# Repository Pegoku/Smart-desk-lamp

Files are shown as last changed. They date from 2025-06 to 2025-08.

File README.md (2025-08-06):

# Smart Desk Lamp

This is a home assistant controlled CWWW desk lamp with capacitive touch buttons, made with ESPHome and ESP32-C3.

## Why I made it?

I made this project as I wanted to learn more about capacitive touch sensors and how to use them with ESPHome. I also wanted to make a simple desk lamp that could be controlled with Home Assistant.

## Features

- Capacitive touch buttons to control the brightness and color temperature of the LEDs.
- Home Assistant integration.

## Images

Final Build:

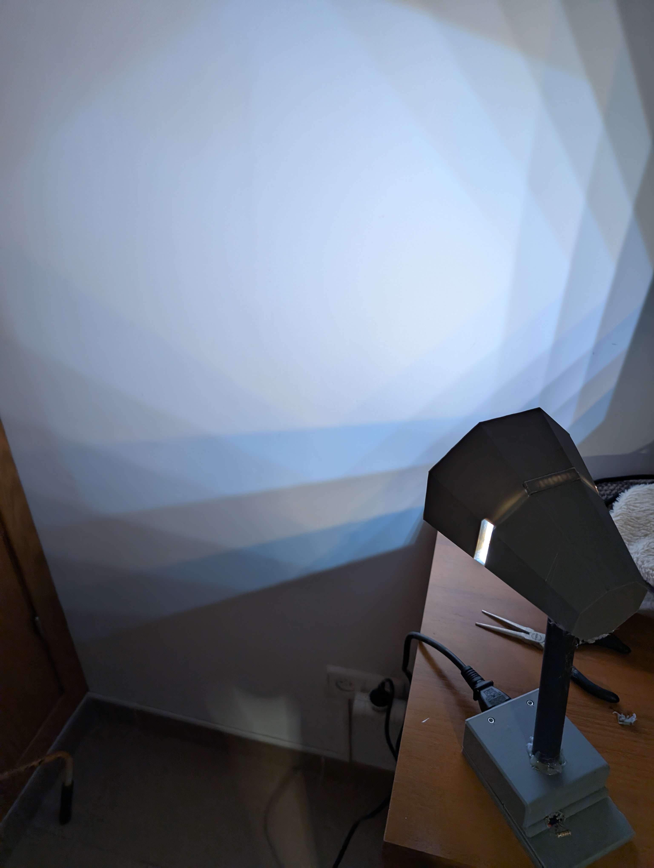
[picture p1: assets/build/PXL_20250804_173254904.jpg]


<details>
  <summary>Case/Assembly</summary>

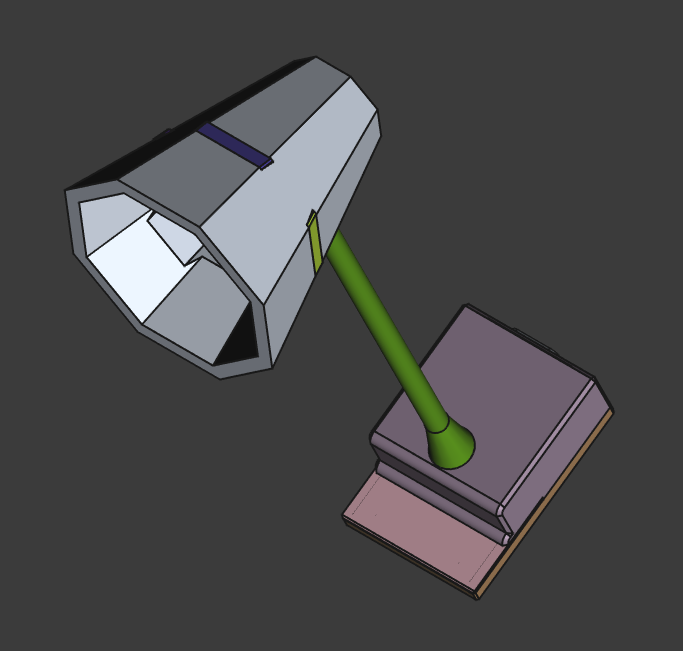
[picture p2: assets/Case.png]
Final


</details>
<details>
  <summary>Main Schematic</summary>
  
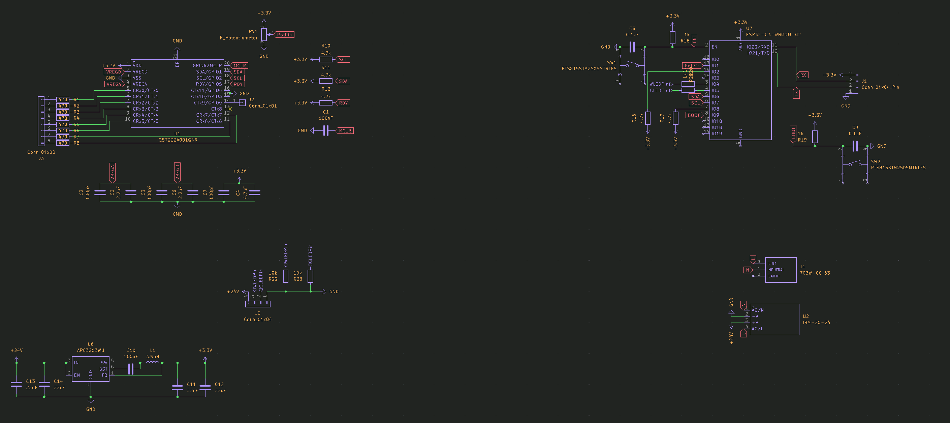
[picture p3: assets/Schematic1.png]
schematic


</details>
<details>
  <summary>Main PCB</summary>

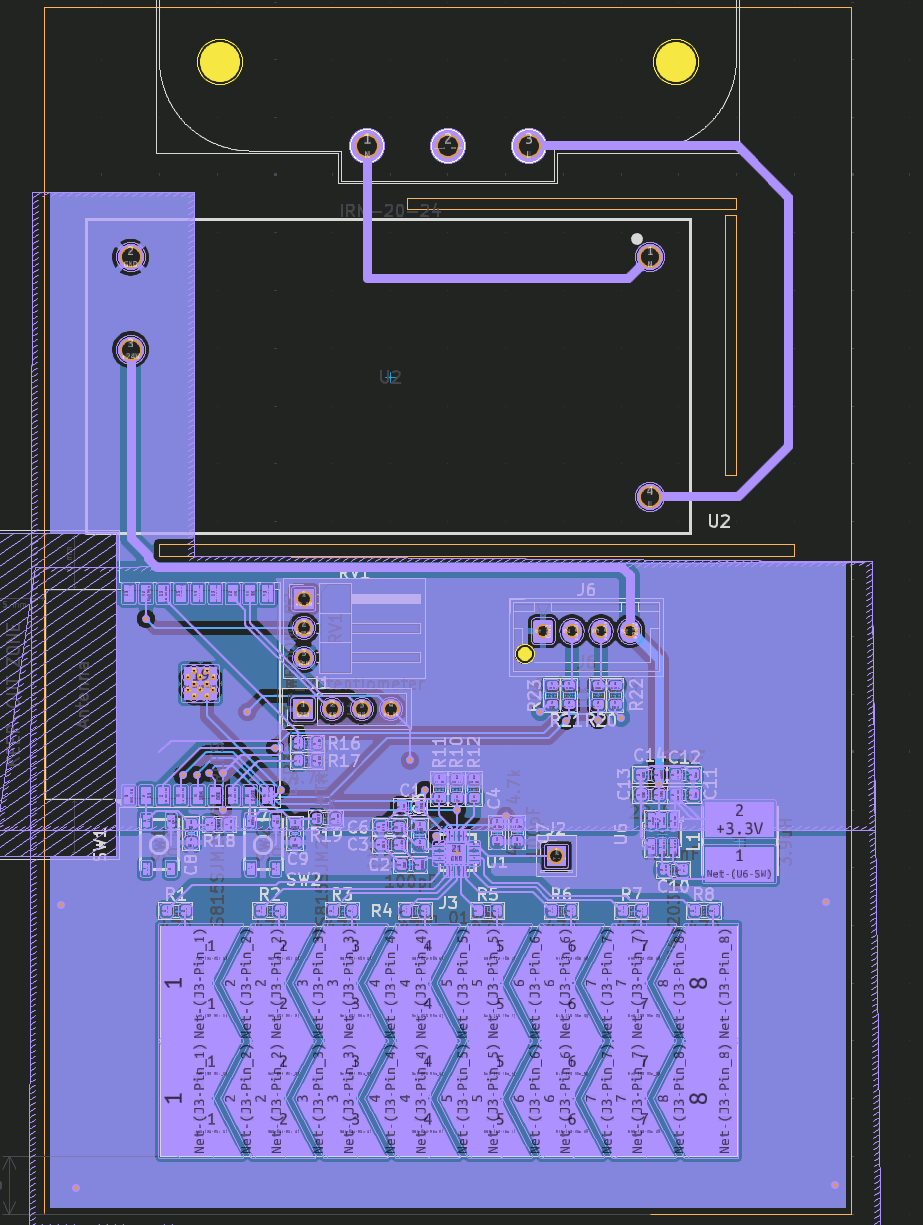
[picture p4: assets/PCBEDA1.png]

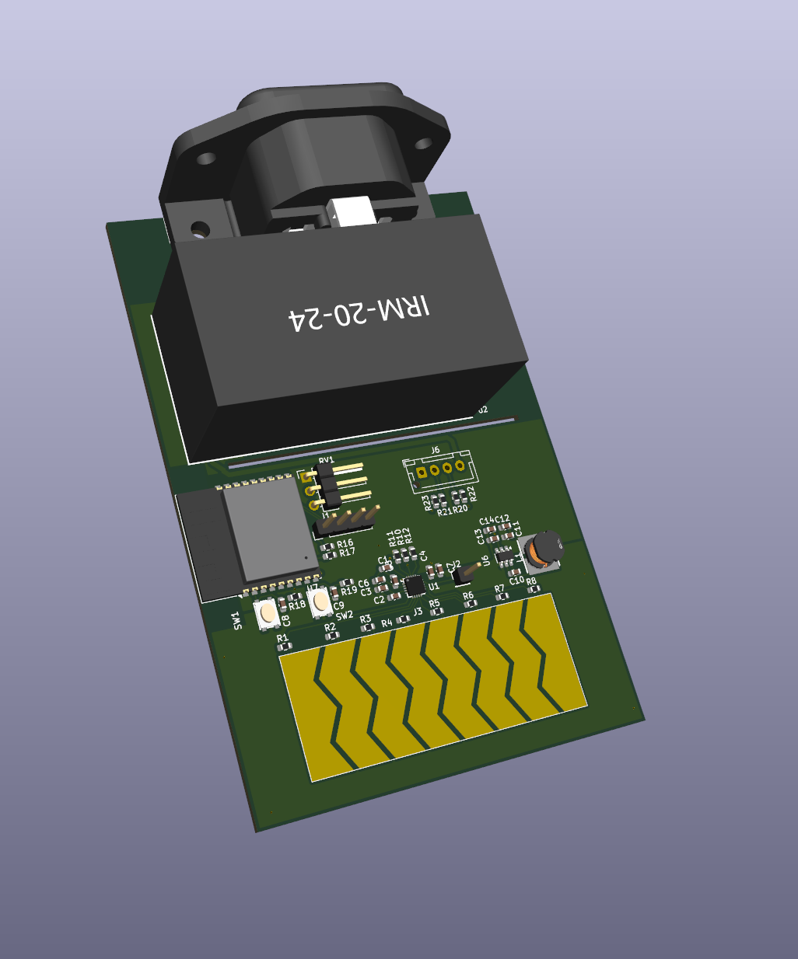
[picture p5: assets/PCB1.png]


</details>

</details>
<details>
  <summary>LED Schematic</summary>
  
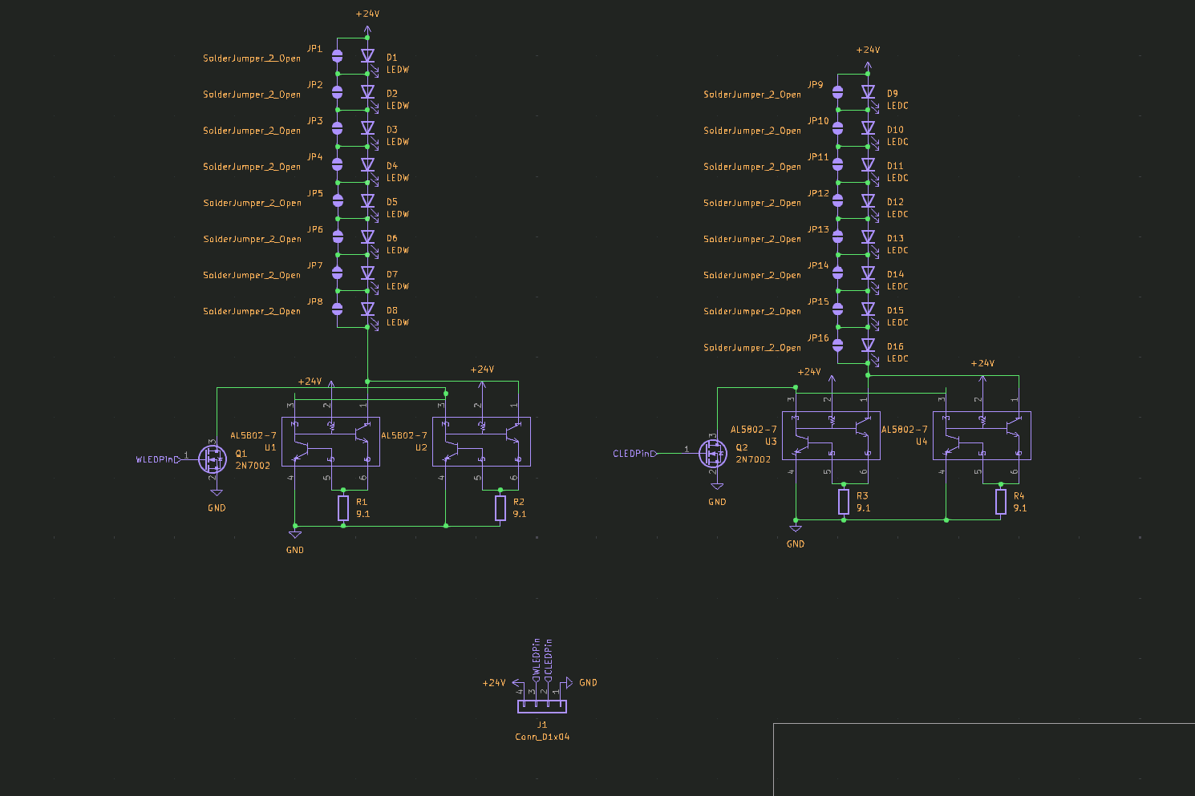
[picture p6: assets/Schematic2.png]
schematic


</details>
<details>
  <summary>LED PCB</summary>

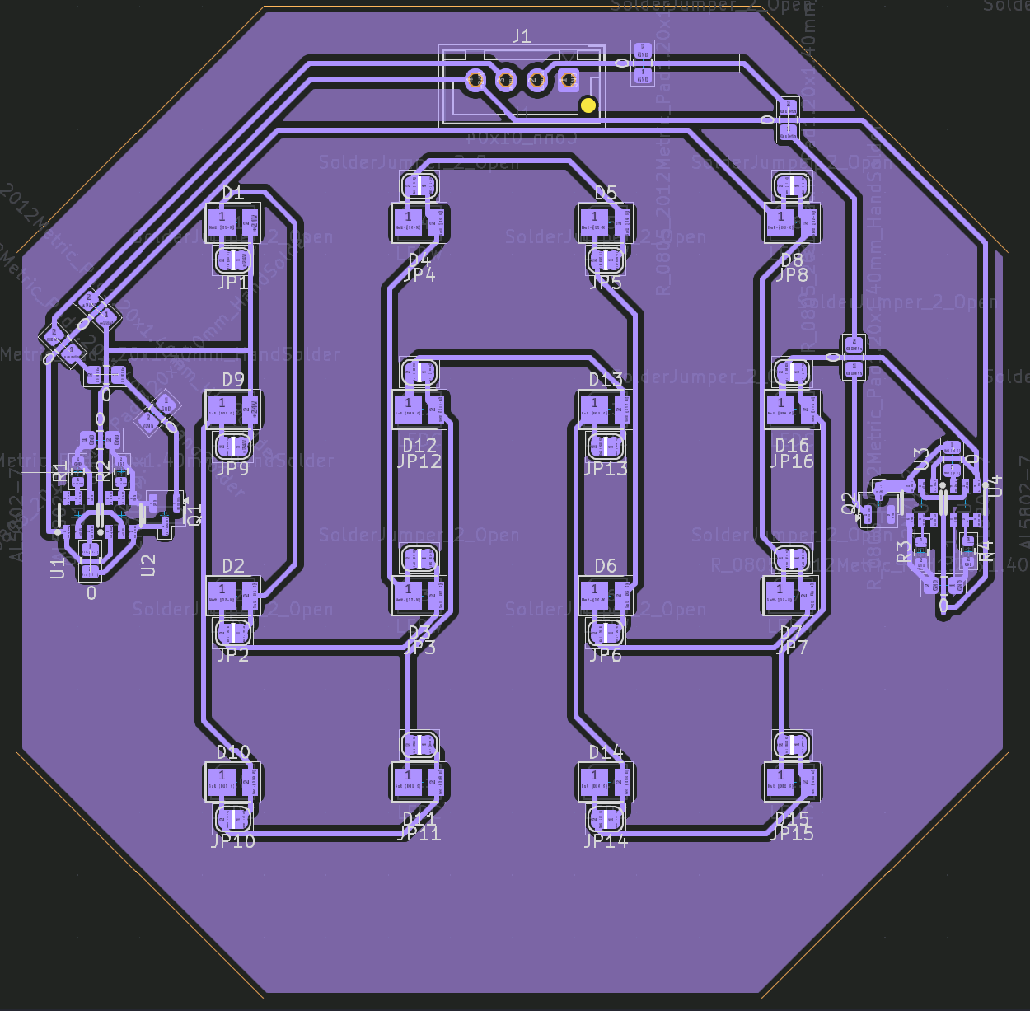
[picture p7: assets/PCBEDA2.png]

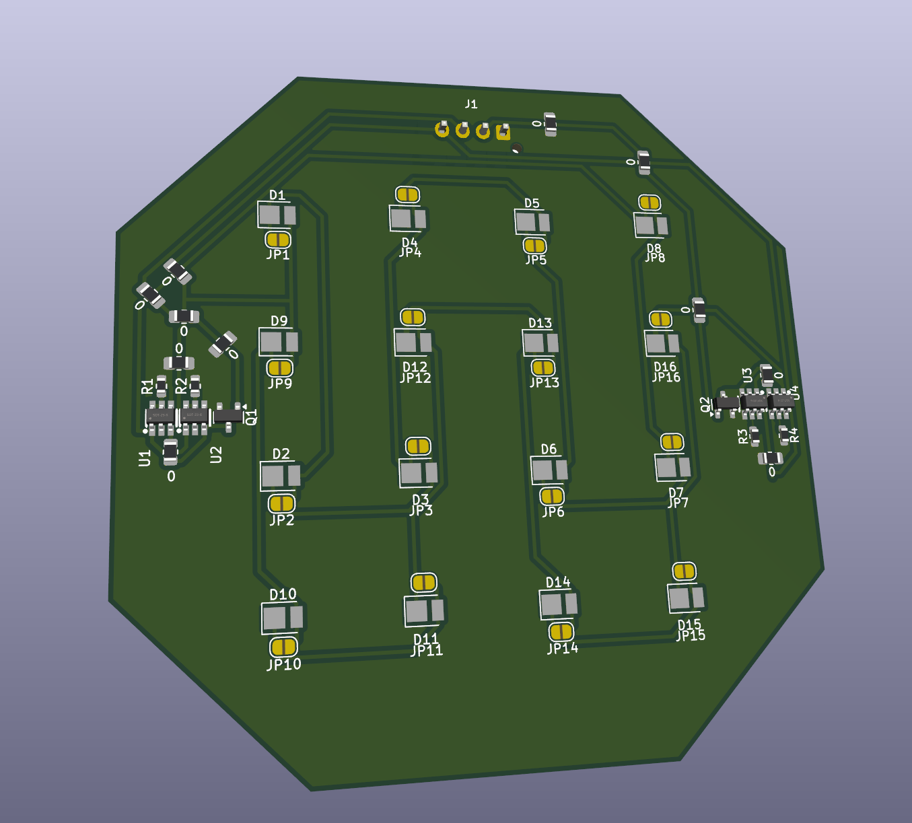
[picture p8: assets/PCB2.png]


</details>

## BOM

| Index | Part Number | What the item is for in your project | Description | Pack Quantity | ID | Unit Price | Total Price | Total (incl. VAT shipping, etc) |
| ----- | --- | --- | --- | --- | --- | --- | --- | --- |
| 1 | IQS7222A001QNR | Capacitive sensor | 9 CHANNEL MUTUAL / 8 SELF-CAPAC | 2 | 1790-IQS7222A001QNRCT-ND | 0.82 | 1.64 | ~140$ |
| 2 | ESP32-C3-WROOM-02-H4 | MCU | RF TXRX MOD BT WIFI PCB TH SMD | 1 | 1965-ESP32-C3-WROOM-02-H4CT-ND | 3.51 | 3.51 | |
| 3 | IRM-20-24 | PSU | AC/DC CONVERTER 24V 22W | 1 | 1866-3040-ND | 9.20 | 9.20 | |
| 4 | AP63203WU-7 | 3.3V buck | IC REG BUCK 3.3V 2A TSOT23-6 | 2 | AP63203WU-7DICT-ND | 0.71 | 1.42 | |
| 5 | AL5802-7 | Led driver | IC LED DRVR LIN PWM 120MA SOT26 | 5 | AL5802-7DICT-ND | 0.23 | 1.15 | |
| 6 | 2N7002 | mosfet to drive the led drivers | MOSFET N-CH 60V 280MA SOT23-3 | 3 | 4878-2N7002CT-ND | 0.12 | 0.36 | |
| 7 | GW JTLPS1.CM-HNKK-XX510-1-150-R33  | 2200K led | LED DURIS E2835 WHT 2200K 2835 | 10 | 475-GWJTLPS1.CM-HNKK-XX510-1-150-R33CT-ND | 0.067 | 0.67 | |
| 8 | GW JTLPS1.CM-JNKN-XX51-1-150-R33 | 6500K led | LED DURIS E2835 WHITE 6500K 2835 | 10 | 475-GWJTLPS1.CM-JNKN-XX51-1-150-R33CT-ND | 0.067 | 0.67 | |
| 9 | SRR5018-3R9Y | inductor | FIXED IND 3.9UH 2A 55 MOHM SMD | 2 | 118-SRR5018-3R9YCT-ND | 0.64 | 1.28 | |
| 10 | 12mm LED Gooseneck | 12mm LED Gooseneck | 30 cm silver, Outer M10 – Outer M10 | 1 | https://es.aliexpress.com/item/1005007938186623.html  | 11.50 | 11.50 | |
| 11 | 703W-00/53 | Power Connector | PWR ENT RCPT IEC320-C14 PNL SLDR | 1 | Q219-ND | 1.54 | 1.54 | |
| 12 | MF72-005D7 | Inrush current limiter | ICL 5 Ω 20% 2A 9 mm | 2 | 317-1148-ND | 0.43 | 0.86 | |
| 13 | M3x30 mm 4762 | M3x30 mm 4762 | M3x30 mm 4762 | 1 | https://www.aliexpress.com/item/1005006453614010.html | 3.105 | 3.105 | |
| 14 | M10 nut | M10 nut | M10 nut | 1 | https://www.aliexpress.com/item/1005007593861199.html | 3.0935 | 3.0935 | |
| 15 | Soldering iron heatset insert tips | Soldering iron heatset insert tips | Soldering iron heatset insert tips  | 1 | https://www.aliexpress.com/item/1005008493831823.html | 21.3785 | 21.3785 | |
| 16 | M3x6 mm 4762 | M3x6 mm 4762 | M3x6 mm 4762 | 1 | https://www.aliexpress.com/item/1005006453614010.html | 2.139 | 2.139 | |
| 17 | Wood Filament | Wood Filament | Wood Filament | 0 | https://www.aliexpress.com/item/1005006685394618.html | 38.1685 | 0 | |
| 18 | 30 cm JST XH 4P | 30 cm JST XH 4P | 30 cm JST XH 4P | 1 | https://www.aliexpress.com/item/1005008319201640.html | 2.5645 | 2.5645 | |
| 19 | CL10A104KA8NNNC | Passive | CAP CER 0.1 µF 25 V X5R 0603 | 10 | 1276-1857-1-ND | 0.028 | 0.28 | |
| 20 | CL10A475KQ8NNNC | Passive | CAP CER 4.7 µF 6.3 V X5R 0603 | 10 | 1276-1045-1-ND | 0.008 | 0.08 | |
| 21 | CL10A225KQ8NNNC | Passive | CAP CER 2.2 µF 6.3 V X5R 0603 | 10 | 1276-1183-1-ND | 0.032 | 0.32 | |
| 22 | CL10A226MQ8NRNC | Passive | CAP CER 22 µF 6.3 V X5R 0603 | 5 | 1276-1193-1-ND | 0.22 | 1.10 | |
| 23 | CL10A104KA8NNNC | Passive | CAP CER 0.1 µF 25 V X5R 0603 | 10 | 1276-1857-1-ND | 0.028 | 0.28 | |
| 24 | CL05C101JB5NNNC | Passive | CAP CER 100 pF 50 V C0G/NP0 0402 | 10 | 1276-1025-1-ND | 0.003 | 0.03 | |
| 25 | 61300411121 | Passive | CONN HEADER VERT 4POS 2.54 mm | 2 | 732-5317-ND | 0.17 | 0.34 | |
| 26 | CRCW0603470MJPEAHR | Passive | RES SMD 470 MΩ 5% 1/10 W 0603 | 10 | 541-470MAHCT-ND | 0.151 | 1.51 | |
| 27 | RC0603FR-074K7L | Passive | RES 4.7 KΩ 1% 1/10 W 0603 | 10 | 311-4.70KHRCT-ND | 0.009 | 0.09 | |
| 28 | RC0603FR-071KL | Passive | RES 1 KΩ 1% 1/10 W 0603 | 10 | 311-1.00KHRCT-ND | 0.009 | 0.09 | |
| 29 | RC0603FR-0710KL | Passive | RES 10 KΩ 1% 1/10 W 0603 | 10 | 311-10.0KHRCT-ND | 0.009 | 0.09 | |
| 30 | PTS815SJM250SMTRLFS | Esp32 buttons | SWITCH TACTILE SPST-NO 0.05 A 12 V  | 4 | CKN12215-1-ND | 0.22 | 0.88 | |
| 31 | PCB | PCB | PCBs + stencil | 1 | jlcpcb.com | 53.03 | 53.03 | |
| 32 | ERJ-6GEY0R00V | 0 ohm jumper | RES SMD 0 OHM JUMPER 1/8W 0805 | 20 | P0.0ACT-ND | 0.02360 | 0.59 | |

## Configuration

Remember to set your secrets in [secrets.yaml](Code/secrets.example.yaml).

All firmware configuration lives in [code.yaml](Code/code.yaml):
PS: This configuration is for reference only, The final configuration will be for the ESP32-S2. You'll also have to configure the devices you want to control in Home Assistant.

```yaml
esphome:
  name: desklight
  friendly_name: desklight

esp32:
  board: esp32-c3-devkitm-1
  framework:
    type: arduino

# Enable logging
logger:

# Enable Home Assistant API
api:
  encryption:
    key: !secret api_key

ota:
  - platform: esphome
    password: !secret ota_password

wifi:
  ssid: !secret wifi_ssid
  password: !secret wifi_password

  # Enable fallback hotspot (captive portal) in case wifi connection fails
  ap:
    ssid: "desklight Fallback Hotspot"
    password: "wHjqyQOLnaPa"

i2c:
  sda: GPIO6
  scl: GPIO7
  frequency: 800kHz
  scan: true

mpr121:
  id: mpr121_component
  address: 0x5A
  touch_debounce: 1
  release_debounce: 1
  touch_threshold: 10
  release_threshold: 7

binary_sensor:
  - platform: mpr121
    id: touch_key0
    channel: 0
    name: "Touch Key 0"
    touch_threshold: 12
    release_threshold: 6

light:
  - platform: cwww
    name: "Livingroom Lights"
    cold_white: WLight
    warm_white: CLight
    cold_white_color_temperature: 6500 K
    warm_white_color_temperature: 2200 K
    constant_brightness: true

output:
  - platform: ledc
    id: WLight
    pin: GPIO4
    frequency: 1000 Hz
  - platform: ledc
    id: CLight
    pin: GPIO5
    frequency: 1000 Hz

captive_portal:
```

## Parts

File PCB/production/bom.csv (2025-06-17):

Designator | Footprint | Quantity | Value | LCSC Part #
C1, C10 | 0603 | 2 | 100nF
C11, C12, C13, C14 | 0603 | 4 | 22uF
C2, C5, C7 | 0603 | 3 | 100pF
C3, C6 | 0603 | 2 | 2.2uF
C4 | 0603 | 1 | 4.7uF
C8, C9 | 0603 | 2 | 0.1uF
J1 | PinHeader_1x04_P2.54mm_Vertical | 1 | Conn_01x04_Pin
J2 | PinHeader_1x01_P2.54mm_Vertical | 1 | Conn_01x01
J3 | TouchSlider-8_50x20mm | 1 | Conn_01x08
J4 | QUALTEK_703W-00_53 | 1 | 703W-00_53
J6 | JST_XH_B4B-XH-AM_1x04_P2.50mm_Vertical | 1 | Conn_01x04
L1 | IND-SMD_L5.8-W5.8 | 1 | 3.9uH
R1, R2, R3, R4, R5, R6, R7, R8 | 0603 | 8 | 470
R10, R11, R12, R16, R17 | 0603 | 5 | 4.7k
R18, R19, R20, R21 | 0603 | 4 | 1k
R22, R23 | 0603 | 2 | 10k
RV1 | PinHeader_1x03_P2.54mm_Horizontal | 1 | R_Potentiometer
SW1, SW2 | KEY-SMD_4P-L4.2-W3.25-P2.15-TL | 2 | PTS815SJM250SMTRLFS | C2689510
U1 | WQFN-20_L3.0-W3.0-P0.40-BL-EP1.7 | 1 | IQS7222A001QNR | C3827627
U2 | PWRM-TH_IRM-20-24 | 1 | IRM-20-24 | C194964
U6 | TSOT-23-6 | 1 | AP63203WU
U7 | ESP32-C3-WROOM-02 | 1 | ESP32-C3-WROOM-02

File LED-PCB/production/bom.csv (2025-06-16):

Designator | Footprint | Quantity | Value | LCSC Part #
0_11, 0_10, 0_9, 0_7, 0_6, 0_5, 0_4, 0_2, 0 | 0805 | 9 | R_0805_2012Metric_Pad1.20x1.40mm_HandSolder
0_8, 0_3 | 0805 | 2 | 0
D1, D2, D3, D4, D5, D6, D7, D8 | LED_PLCC_2835 | 8 | LEDW
D10, D11, D12, D13, D14, D15, D16, D9 | LED_PLCC_2835 | 8 | LEDC
J1 | JST_XH_B4B-XH-AM_1x04_P2.50mm_Vertical | 1 | Conn_01x04
Q1, Q2 | SOT-23 | 2 | 2N7002
R1, R2, R3, R4 | 0603 | 4 | 9.1
U1, U2, U3, U4 | SOT-23-6_L2.9-W1.6-P0.95-LS2.8-BR | 4 | AL5802-7 | C129160

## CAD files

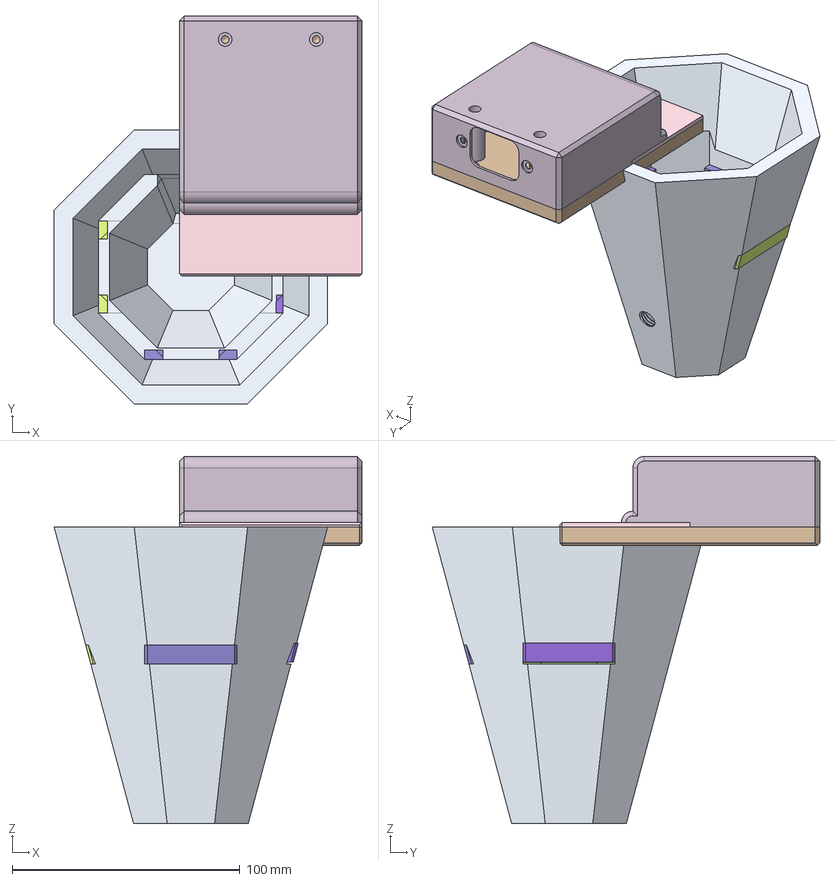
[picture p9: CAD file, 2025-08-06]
CAD/Lamp.step
135.0 x 170.0 x 161.0 mm

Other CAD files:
CAD/Lamp.FCStd

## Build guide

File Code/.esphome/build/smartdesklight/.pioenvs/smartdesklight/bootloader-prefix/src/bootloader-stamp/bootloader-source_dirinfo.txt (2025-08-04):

# This is a generated file and its contents are an internal implementation detail.
# The download step will be re-executed if anything in this file changes.
# No other meaning or use of this file is supported.

method=source_dir
command=
source_dir=/home/pegoku/.platformio/packages/framework-espidf/components/bootloader/subproject
work_dir=

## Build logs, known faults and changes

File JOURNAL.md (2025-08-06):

---
title: "Smart Desk Lamp"
author: "Pegoku"
description: "An ESP32-C3 based Desktop Light with capacitive touch and Home Assistant Integration"
created_at: "2025-06-09"
total_time_spent: "58h"
---

# June 9th: Mockup
To start the project, I wanted to do a mockup of the design.
I drew the idea I had in mind, which was a simple desk LED light, I also wanted it to have capacitive touch buttons to control the brightness, bc, why not?
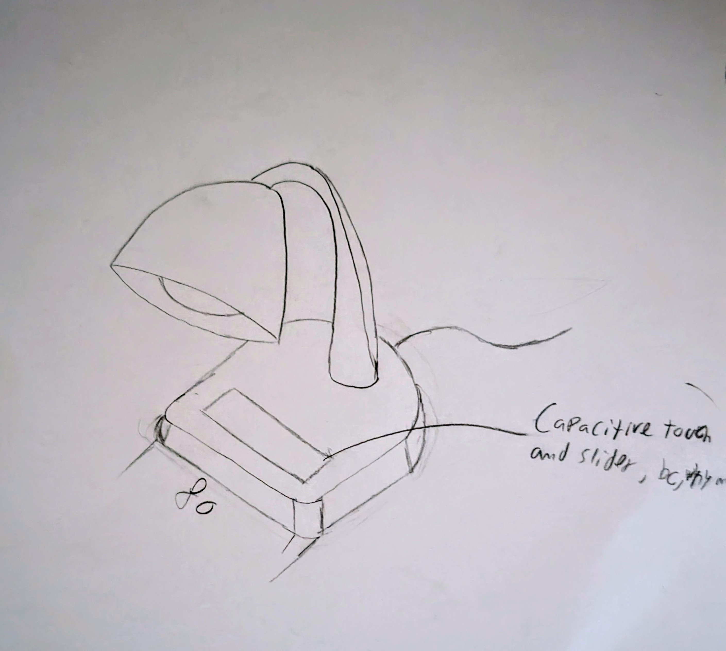
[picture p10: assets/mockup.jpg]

**Total time spent: 2h**

# June 10th: Mockup
Now I had the mockup, and had to start thinking about the components I would need.
To start with, I wanted to use espHome, so I would be using an esp32, as in most of my projects.
I also wanted a way yo control the brightness, so I would need a mosfet (or led driver) to control the LEDs.
Probably a buck PSU for the esp32 will be needed too, and maybe another for the LEDs.

Components I decided to use:
- ESP32-C3-MINI-1-H4
- XLG-20-M (ACDC led driver with PWM and 0-10V dimming)
- IQS7222A001QNR (capacitive touch controller)
- JST XH connector (for the LEDs)
- RS-15-24 (24V PSU)

**Total time spent: 4h**

# June 11th: Continue searching for components and starting the schematic
Yesterday I started looking for components, and had to quit early, so I continued today.
I also thought of removing the XLG-20-M, and using 2 led drivers, warm and cold, to control the color temperature. I'd use this CWWW implementation: https://esphome.io/components/light/cwww.html
Final omponents I decided to use:
PCB1 (aluminum PCB for the LEDs):
- AL5802-7 (LED driver for the LEDs)
- GW JTLPS1.CM-JNKN-XX51-1-150-R33 (cold white LED)
- GW JTLPS1.CM-HNKK-XX510-1-150-R33 (warm white LED)
- JST XH connector (for the LEDs)
PCB2 (main PCB):
- ESP32-C3-WROOM-02-H4
- AP63203WU-7 (buck converter for the ESP32)
- IQS7222A001QNR (capacitive touch controller)
- JST XH connector (for the LEDs)
- RS-15-24 (24V PSU)
- 6100.3300 (AC C14 connector)
- [6.3mm faston terminal](https://es.aliexpress.com/item/1005007347459855.html)
- 
- SN-02C (crimp jaw for the terminals)

I also found this documentation for capacitive touch buttons: https://ww1.microchip.com/downloads/en/Appnotes/Capacitive-Touch-Sensor-Design-Guide-DS00002934-B.pdf

I started designing the schematic, started with the capacitive touch controller. For that I designed a simple footprint for the electrodes.

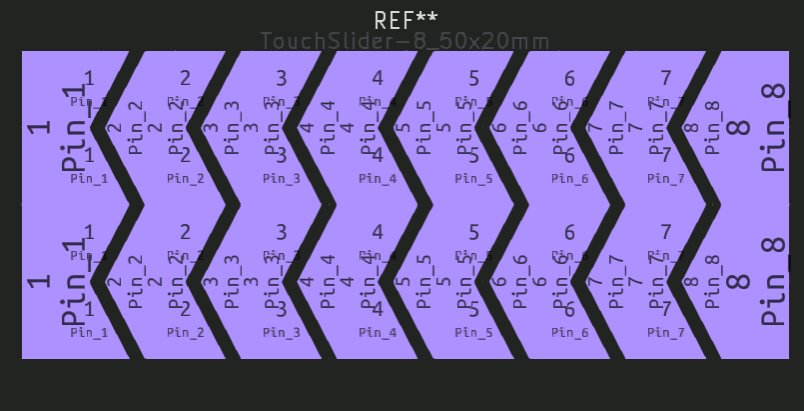
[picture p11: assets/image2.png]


Final capacitive circuit:

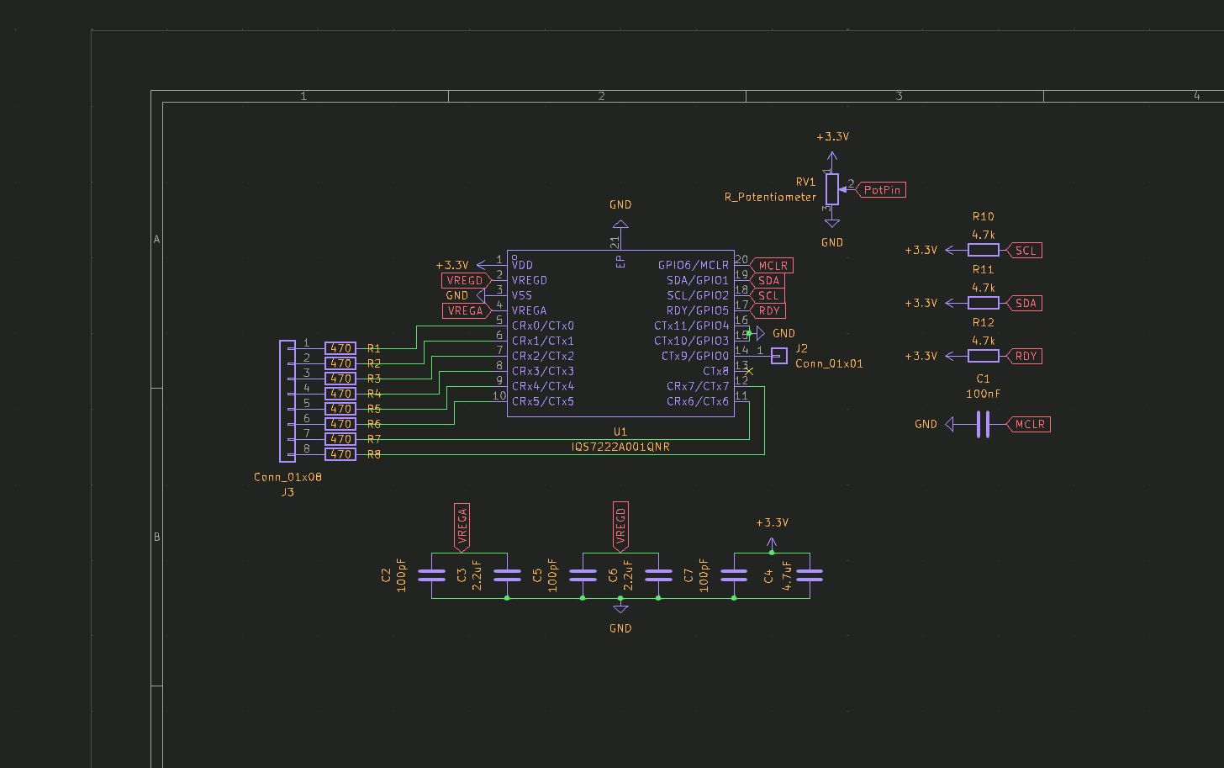
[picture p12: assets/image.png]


PS: It was my first time designing a capacitive touch circuit, so I hope it works.

**Total time spent: 6h**

# June 12th: Continuing the schematic
Today I continued the schematic, more specifically the ESP32 part.
I first designed the esp32 circuit as if it was an esp32-S2, but then I realized it was an ESP32-C3, so I had to change strapping pins i used.

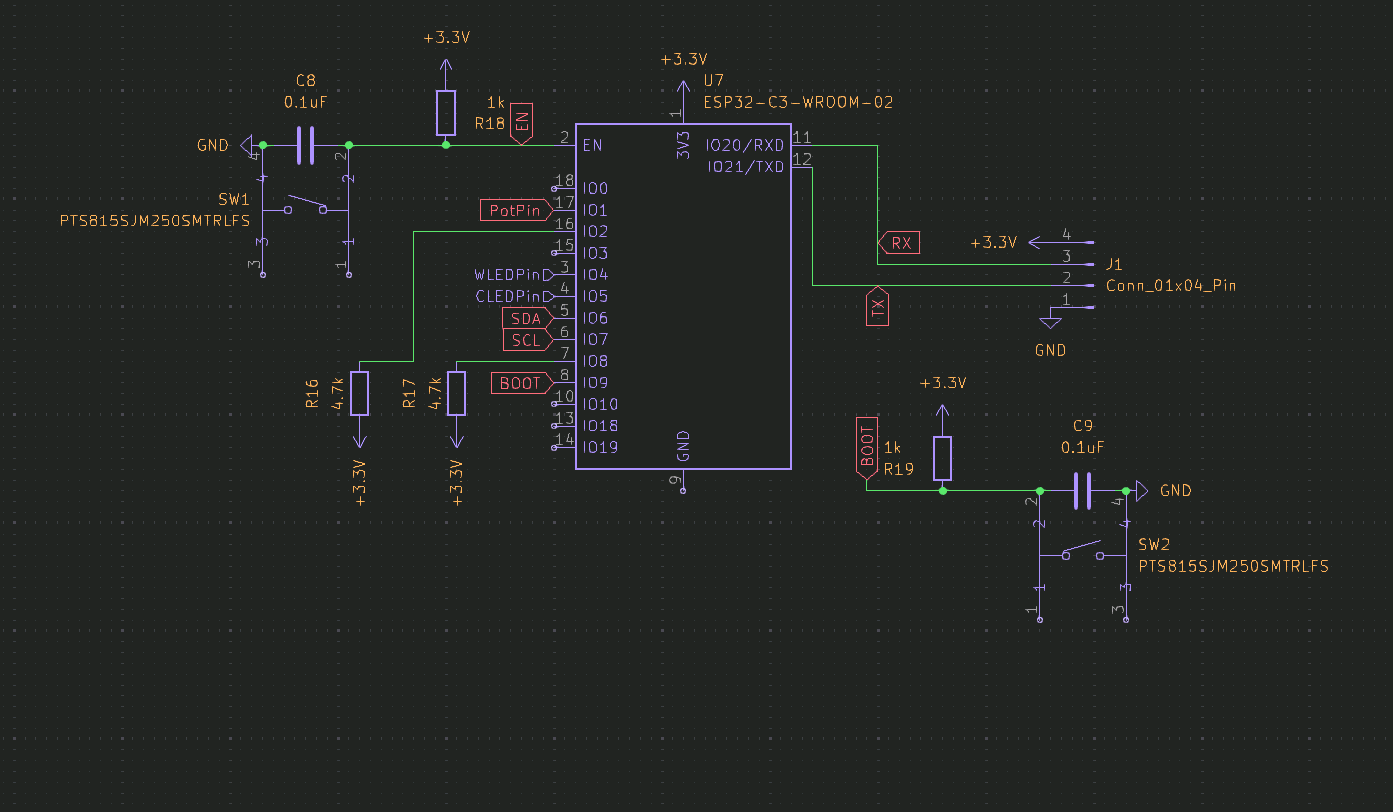
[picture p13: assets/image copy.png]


I also added the buck converter, and the power supply connector.

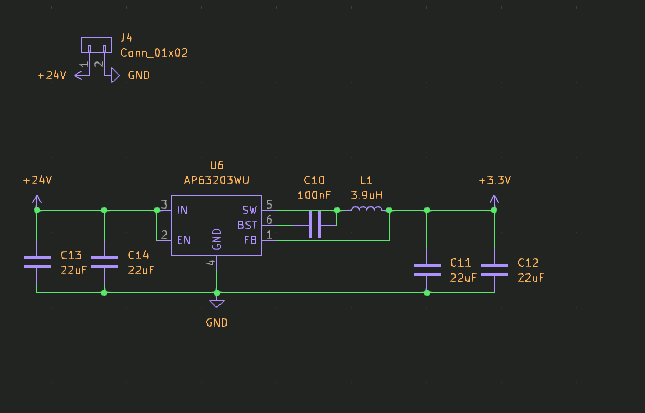
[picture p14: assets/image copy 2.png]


**Total time spent: 3h**

# June 13th: Finishing the schematic
Today I finished the schematic, I added the LED driver and the LEDs. I also added the connectors for the LEDs.

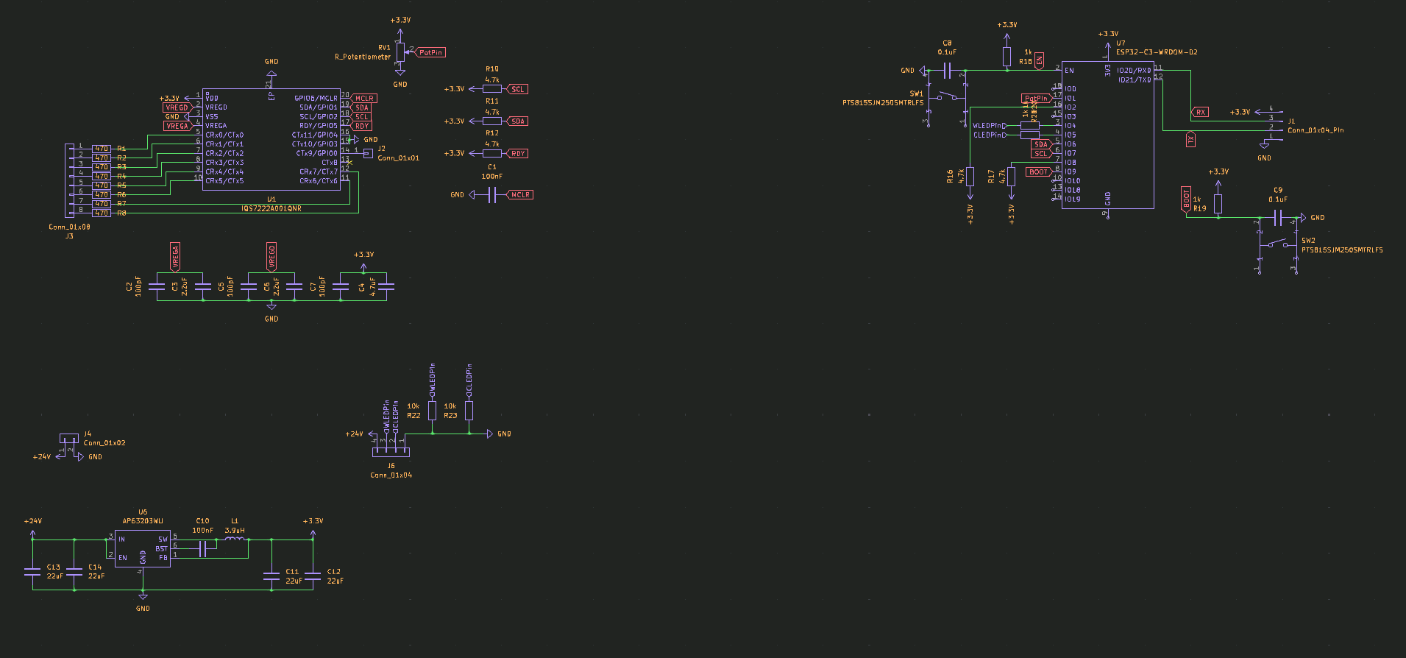
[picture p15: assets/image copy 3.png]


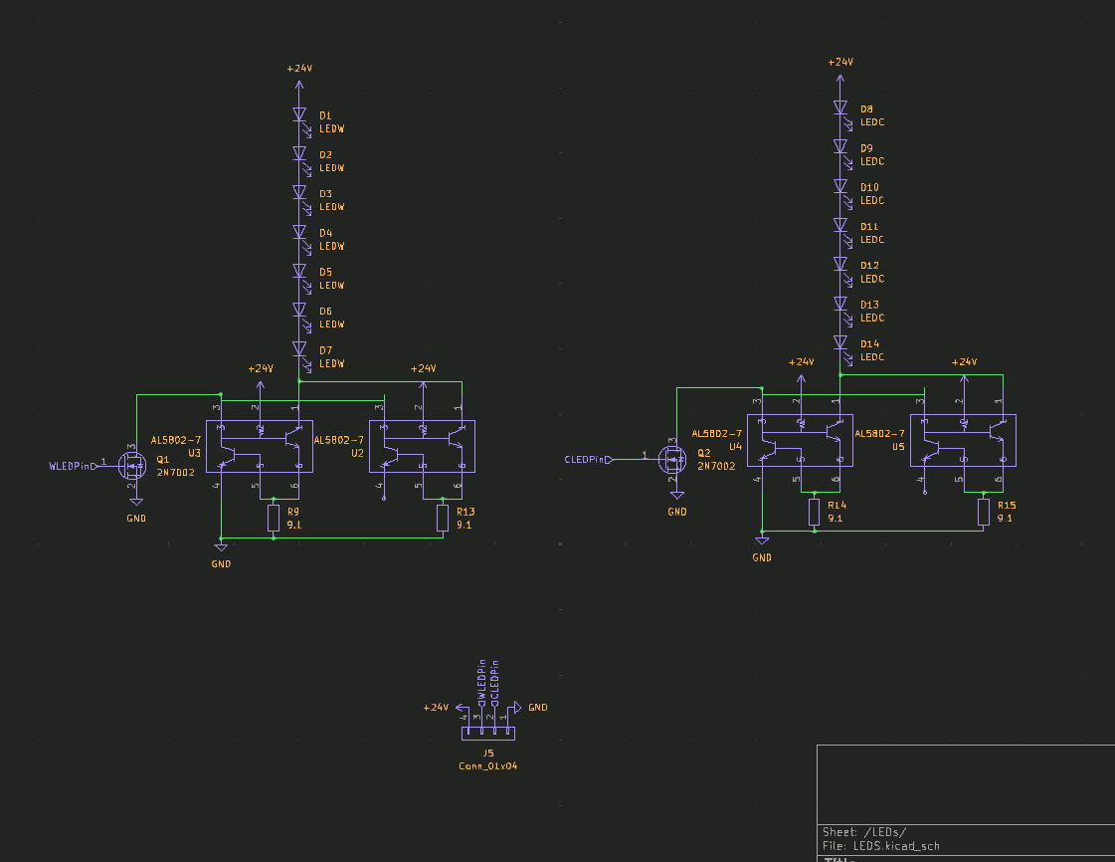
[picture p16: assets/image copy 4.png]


**Total time spent: 1.5h**

# June 14th: PCB design
Today I started the PCB design, I first designed the PCB for the capacitive touch controller (Main PCB), as it didn't seem too hard. I used 2 layers with FR4, as it was cheap and easy to work with.

After wiring everything, I finished the pcb. I'm not sure if the electrodes are too close, but I hope it works.

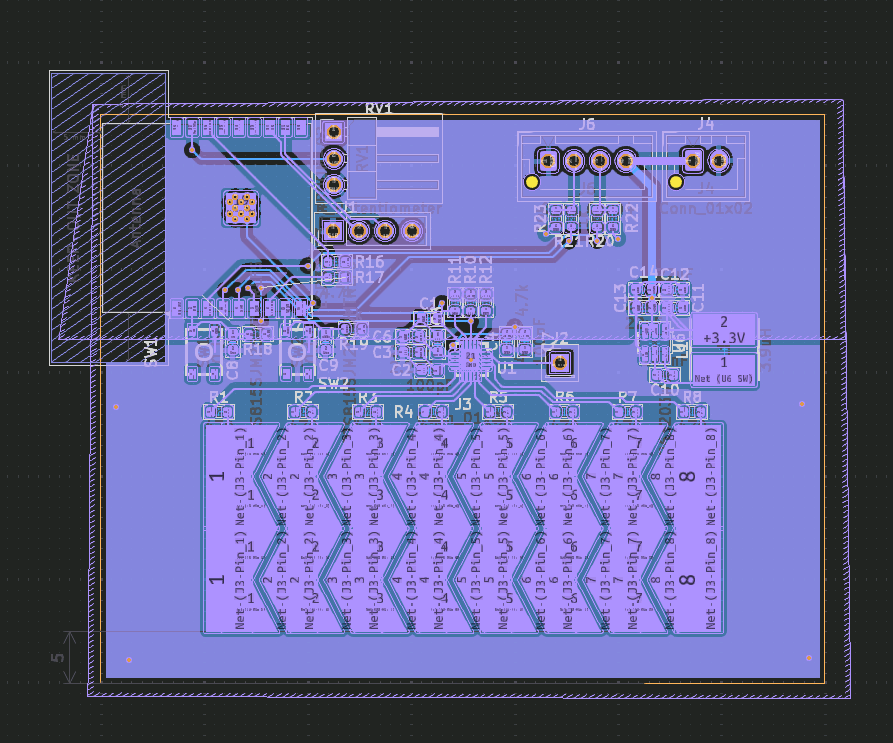
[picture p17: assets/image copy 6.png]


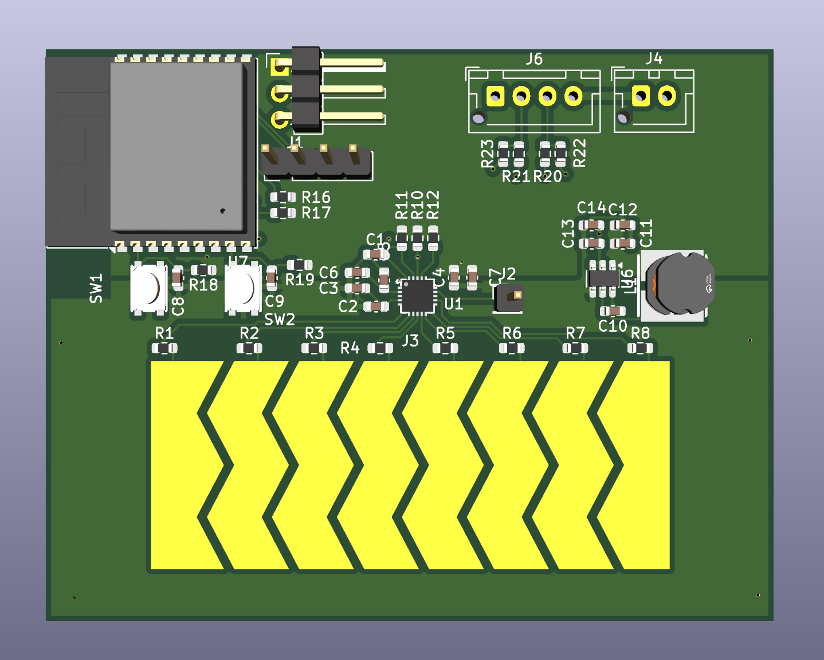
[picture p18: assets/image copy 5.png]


Then I started the PCB for the LEDs. I wanted it to be an Aluminum PCB, as it is the optimal choice for medium to high-power leds, so I think it would be a perfect fit for the LED PCB. Sadly, Aluminum PCBs are one-sided, which was complicated quite a bit the design.
I tried for hours to find a way to make it work, but I couldn't find a way to route the PCB without using vias, which is not possible with Aluminum PCBs. So I gave up for the day, and decided to try again tomorrow.
This is what I have so far: 

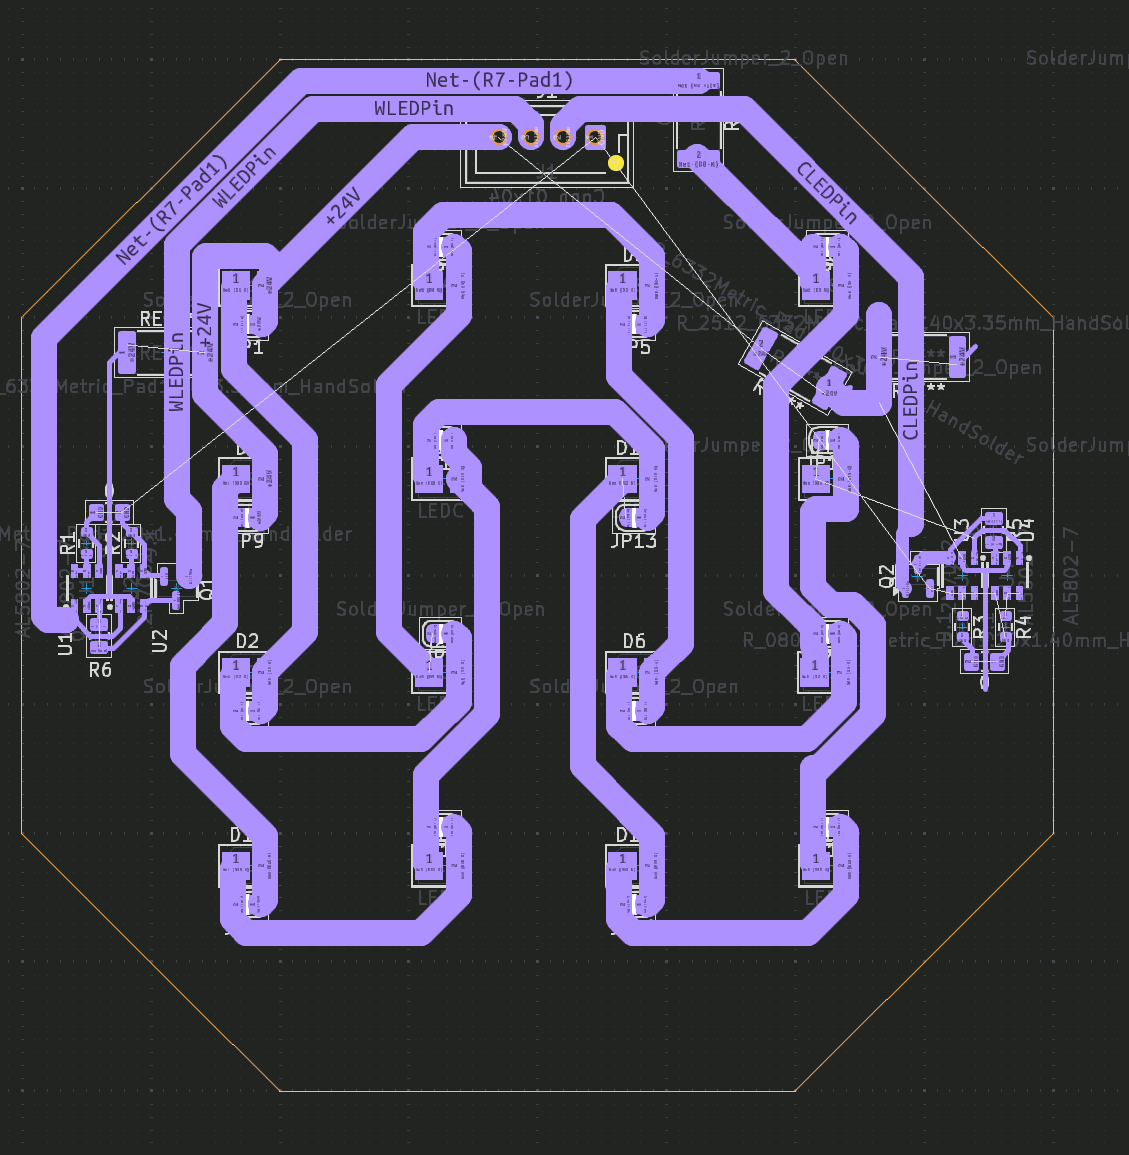
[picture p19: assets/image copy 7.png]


**Total time spent: 5h**

# June 15th: Finish PCB design
Today I finished the PCB design, I found ~~the perfect~~ a working arrangement!
It took me a while, but thanks to a new set of eyes, I finally managed to route the PCB without using vias.
I decided on using 0 ohm resistors as jumpers to create a virtual 2nd layer. IIRC, I saw this being used in a video from GreatScott, so I thought it was a good idea to try it out.

After quite a bit of work, I finally finished the PCB design!

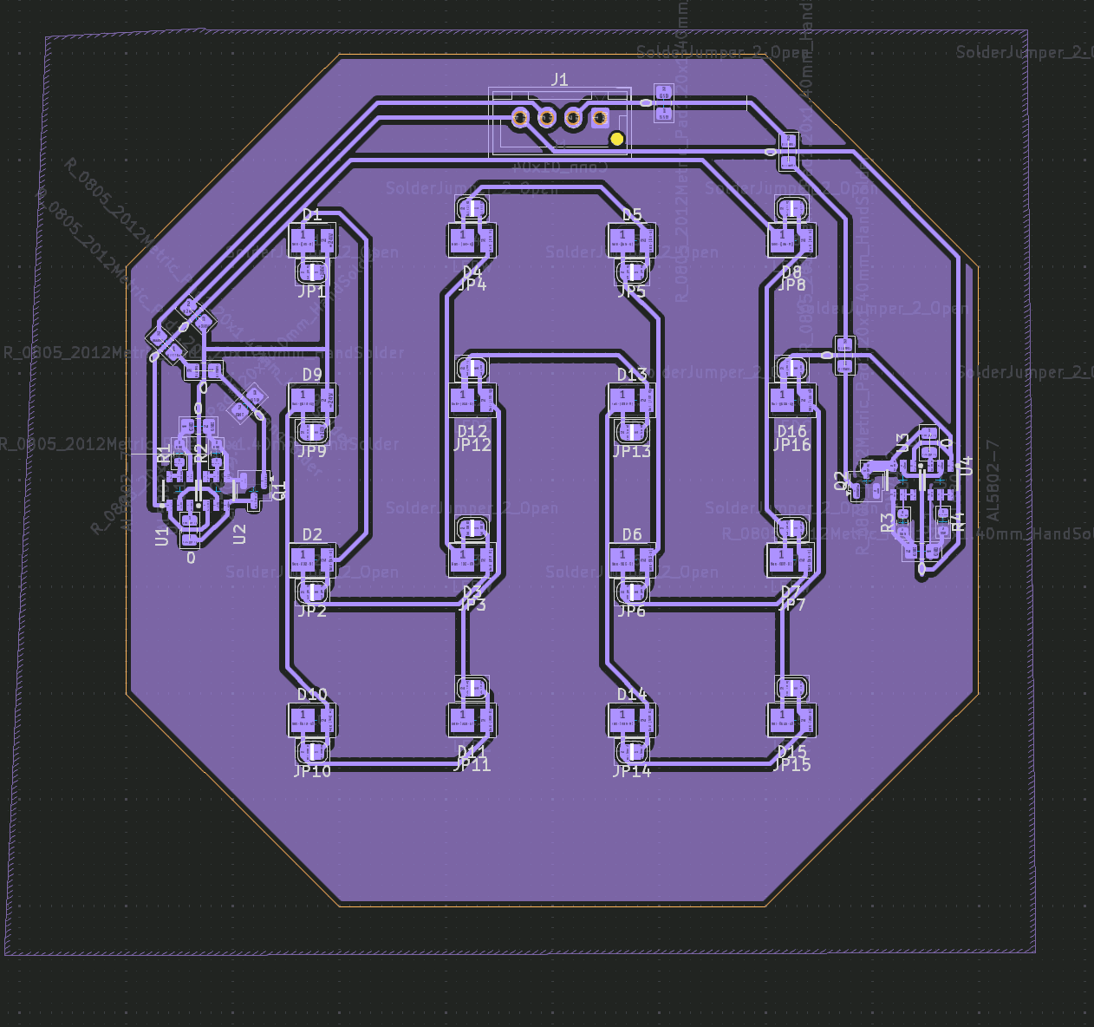
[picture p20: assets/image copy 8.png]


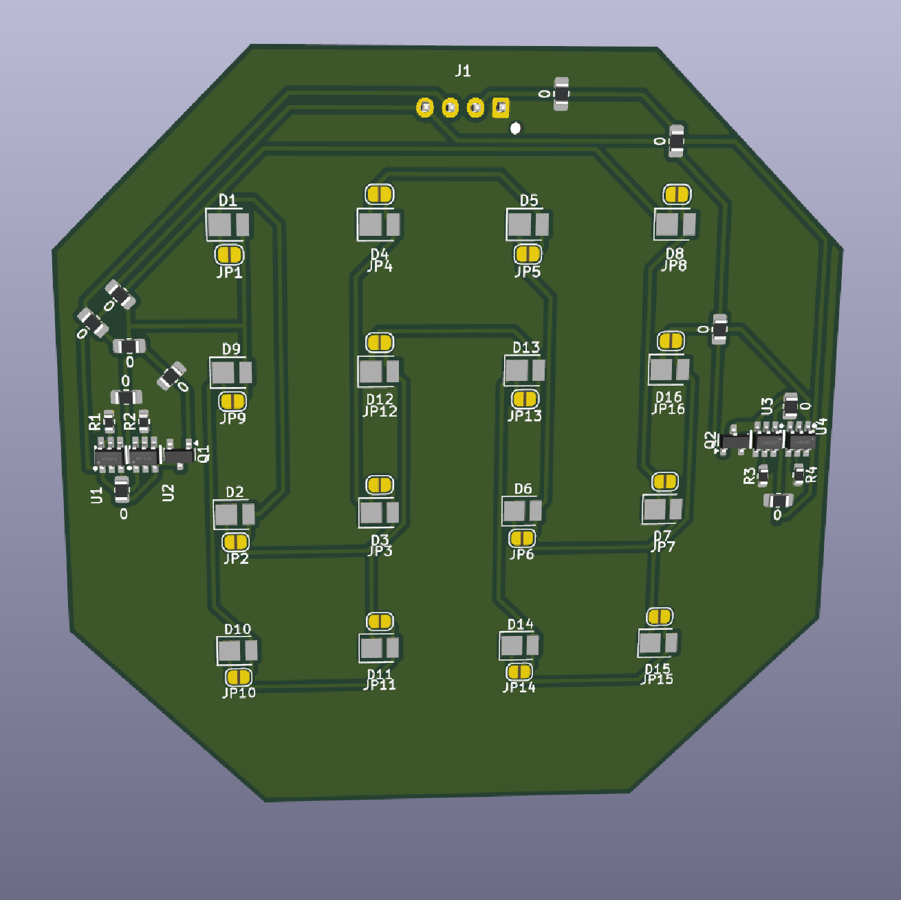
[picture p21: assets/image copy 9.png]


PS: DRC gives quite a few errors bc of the jumpers, but I don't care, as they should work and I don't know how to tell kicad it's a 0-ohm jumper without modifying the schematic.

**Total time spent: 6h**

# June 16th: Start the 3d model
Today I started the 3d model, I wanted to make it simple and base it on the mockup I made at the beginning of the project.
To start with, I searched for a rigid-flexible tube I could use for the top part, as I wanted it to be adjustable. I really didn't know what to search for, so I just searched for "Flexible desk lamp tube" on aliexpress, and started hopping from one product to another until I found this one: https://es.aliexpress.com/item/1005007938186623.html The 30cm silver, Outer M10-Outer M10, seems to work for me, so I added it to the BOM.

Now that I've got all the non-printed items, I started designing the 3d model.
To start with, I designed the LED part, which is the part that will hold the LEDs and the aluminum PCB. I started with a simple cone, but switched to an octagonal prism with taper angle of 15º, as it was easier to design and looked better.

What I have so far:

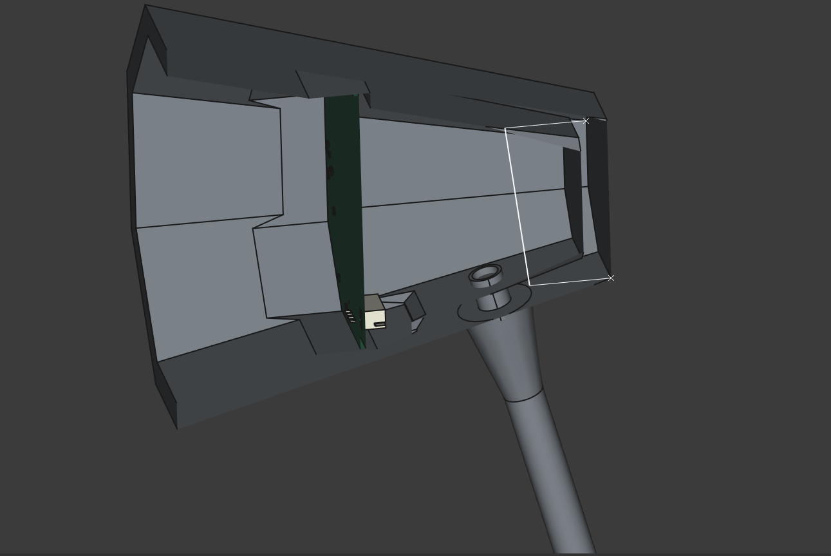
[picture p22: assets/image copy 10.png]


While designing the 3d model, I realized the PSU was quite big, so I searched for a smaller one. I added it to the pcb.

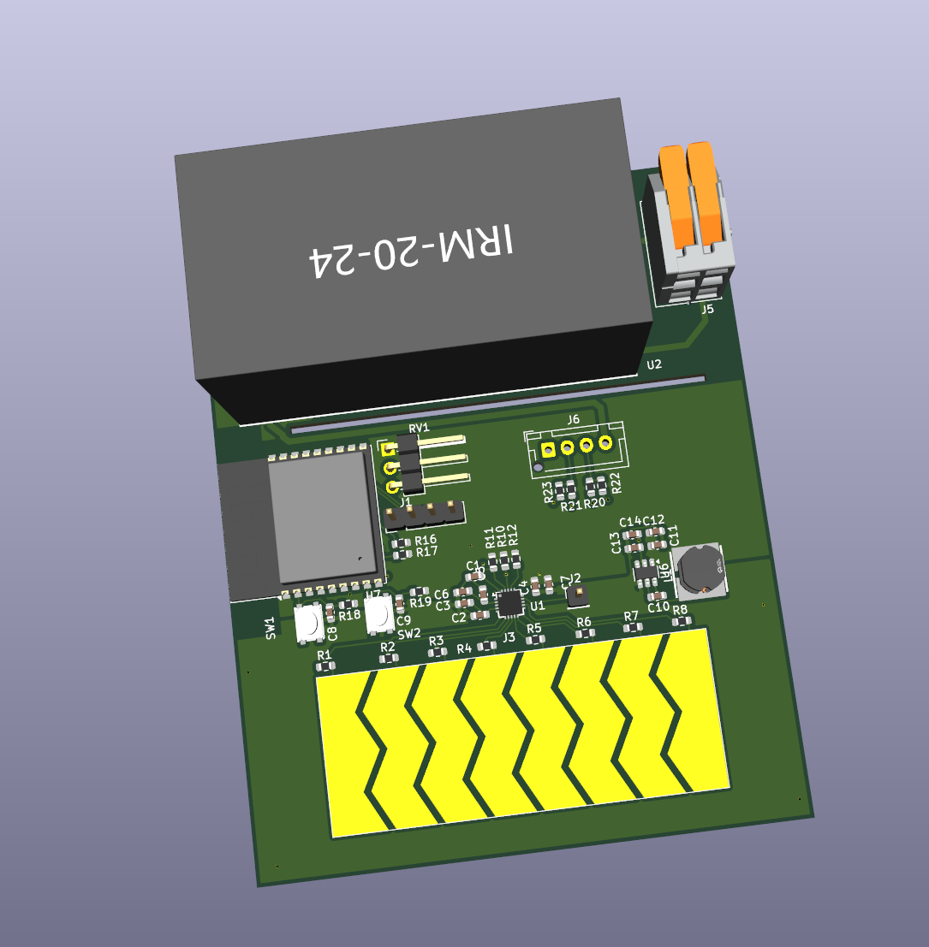
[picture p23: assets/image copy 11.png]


**Total time spent: 5h**

# June 17th: Finish the 3d model and BOM
I had the 3d model almost ready, so I just had to do the base, which was qutie simple. But to make it easier, and stronger, I replaced the original C13 connector with a new THT one, this way I don't need spade connectors to connect it to the PCB.

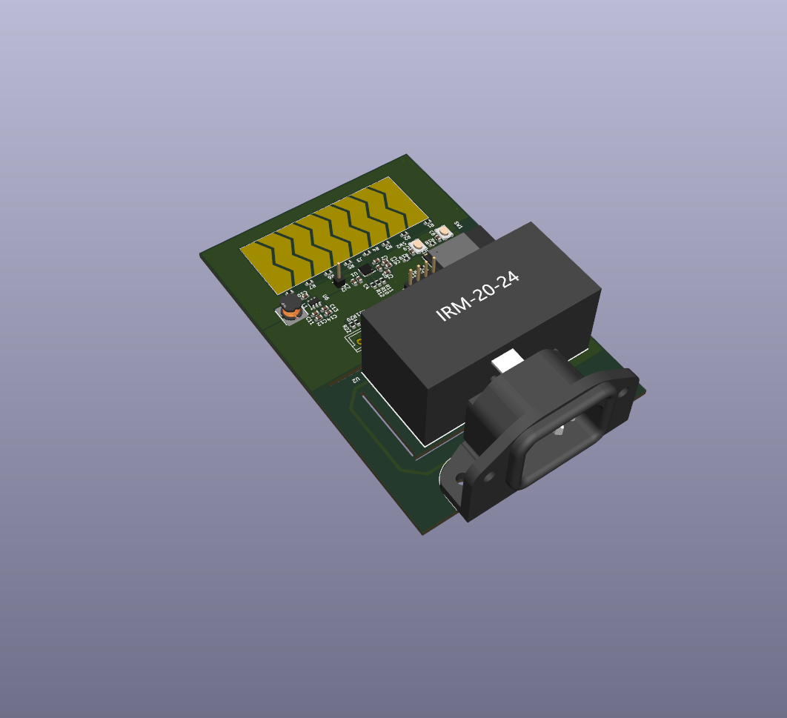
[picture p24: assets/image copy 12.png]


I also added a holder for the LED PCB. I'll use 3d printed clips to hold it in place, probably also a bit of hot glue.

Final result: 

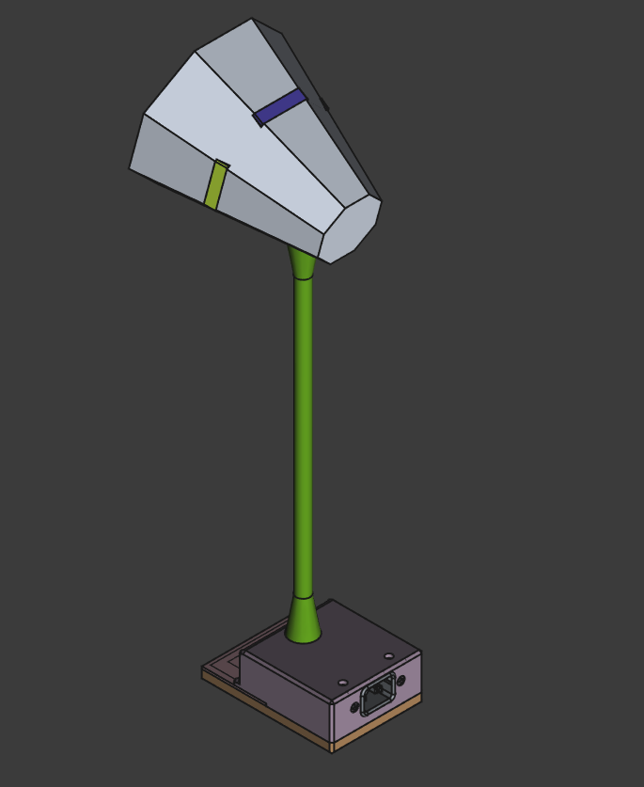
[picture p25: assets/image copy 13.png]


**Total time spent: 6h**

# July 30th: Soldering the PCB
Yesterday I recieved the PCBs, so today I started soldering them. Sadly the solder paste I had was expired and a bit dry, so just added some flux to it and hoped for the best. Soldering worked well enough, I haven't yet tested the board. hope it works.

PS: I plugged the power cord, and it didn't blow up!!

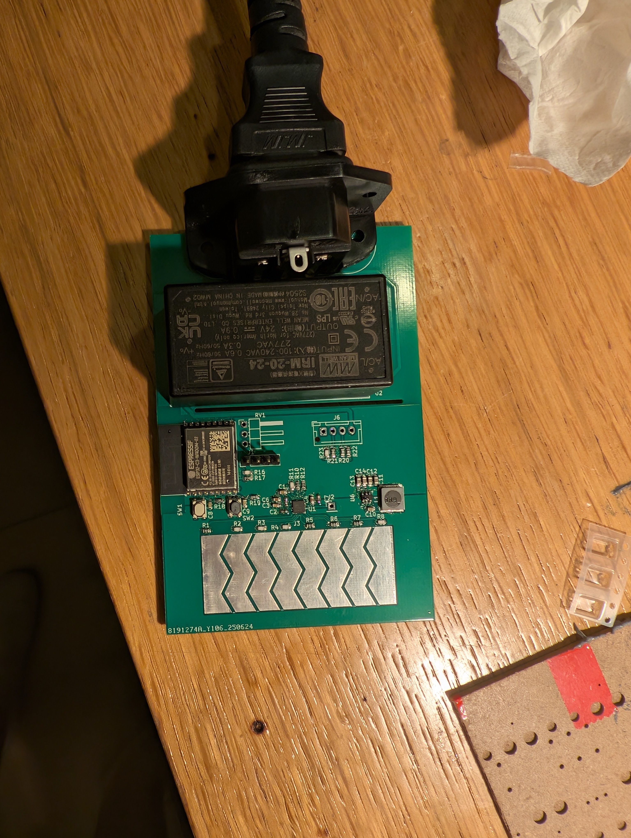
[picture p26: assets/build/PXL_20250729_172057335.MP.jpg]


**Total time spent: 4.5h**

# July 31st: Testing the PCB
Today I started programming the ESP32, I used PlatformIO. First, I created the project, and configured the platformio.ini file to use the ESP32-C3 board.
It didn't work, and I didn't know why, but luckily I found, after quite a lot of messing around that the PCB had a design error, GND wasn't connected!!. Luckily I was able to fix it relatively easily. I just scratched the back of the PCB and bridged a GND via to the GND fill. Then, the board uploaded, but the code didn't run, and I found out it was because I had set the wrong board. I used an adafruit one, and i should have used a generic one. After changing the board, it worked!

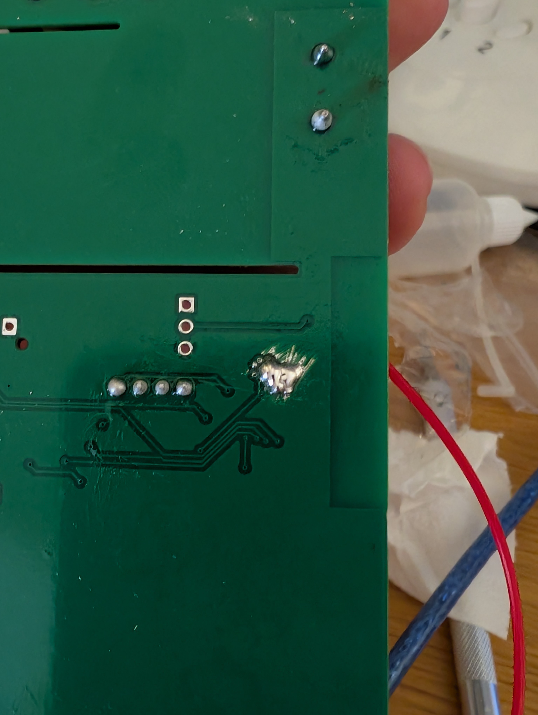
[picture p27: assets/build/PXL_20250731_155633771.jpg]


Now I tried to connect the capacitive touch controller, but it didn't work. It wasn't being detected by the ESP32, so I checked the wiring. I even tried soldering to the QFN pins, but it still didn't work. I ended up giving up, as I didn't find any useful information, as it seems like no one has used this controller with an ESP32 before. I think I'll focus on the LEDs first, and then try to get the capacitive touch working (if I can find a way to do it).

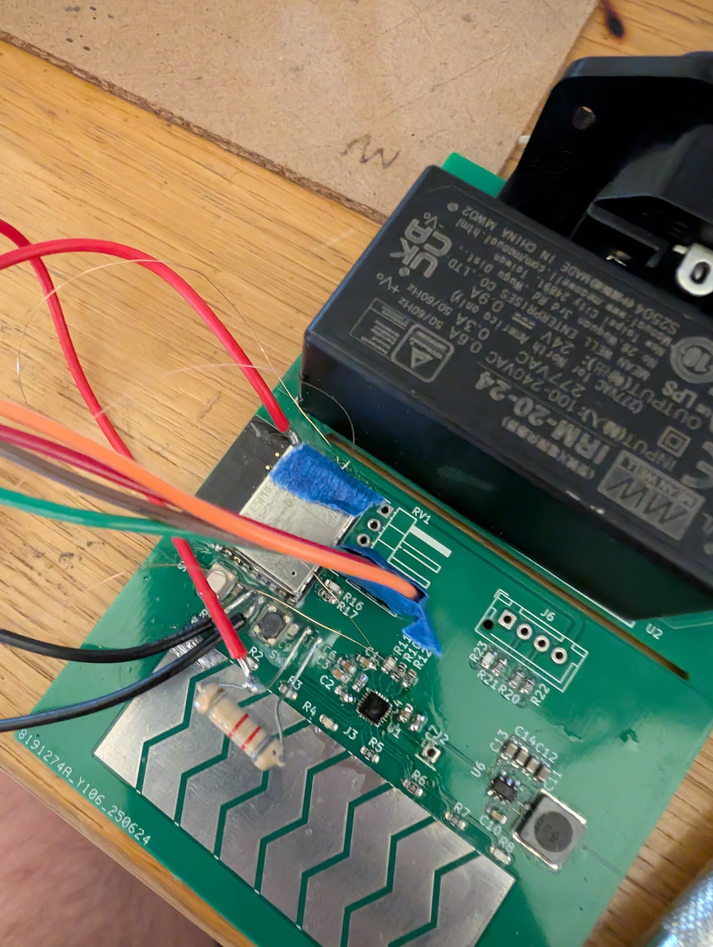
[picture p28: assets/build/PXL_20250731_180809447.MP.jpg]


**Total time spent: 6h**

# August 3rd: PCB worked!... for a moment
Today I soldered the LED PCB. I placed all the LEDs, led drivers, but I found out I hadn't ordered the led driver resistors, so I had to use some 10Ω tht resistors I had lying around. I soldered them, which was hard, and I broke one pad, but I managed to solder them. I also added hot glue to the pcb so the resistors wouldn't fall off and break more pads. Then I tested the LEDs using some voltage, and they worked!
Now I just had to connect the LED PCB to the main PCB, and code ESPHome to control the LEDs.
Luckily that was easy. I was able to do it quite quickly, and I was able to control the LEDs using ESPHome. I also added it to my Home Assistant, so I could control it from there. I even got dimming and color temperature working!

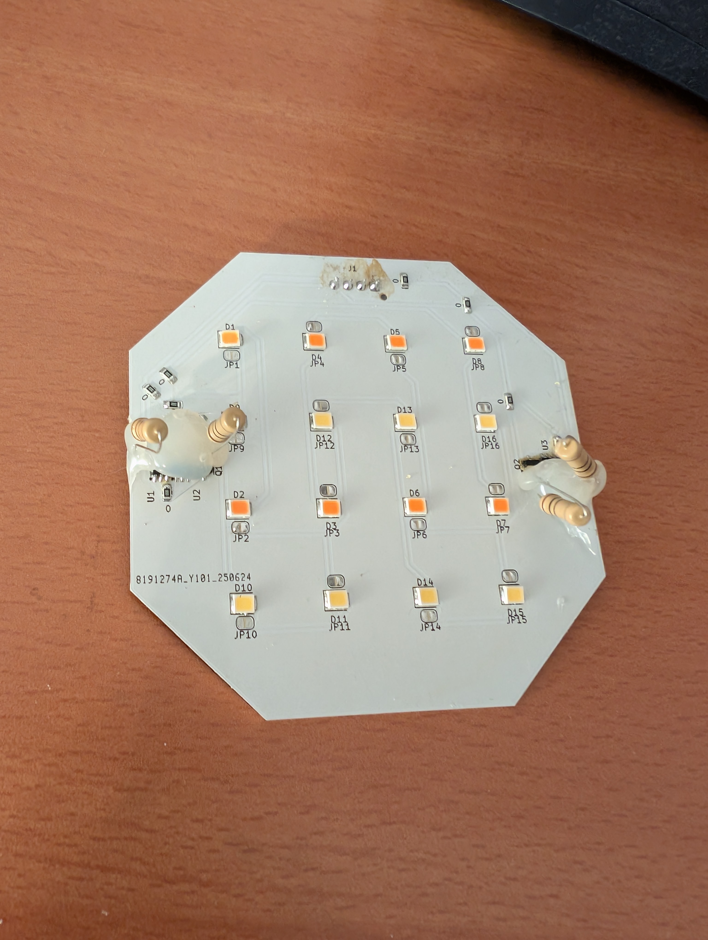
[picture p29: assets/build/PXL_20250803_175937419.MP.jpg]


Sadly, after a few minutes, the LEDs went full brightness, and the ESP32 stopped responding. I tried resetting it, but it didn't work. Then I used my finger to feel the temperature of the ICs, and the 3.3V buck was burning hot. I had to remove the power, and let it cool down. After a while, I tried again, but with no luck. The ESP32 was fried, and the buck converter was also fried. I think the problem was that the buck wasn't being cooled properly. 
Luckily the led drivers were fine, and so were the LEDs, so I could just use the light at full brightness.

**Total time spent: 5h**

# August 4th: Assesmbly of the case
Today, after the disaster yesterday, I decided to assemble the case. I had already printed the parts, so I just had to put them together. Sadly, Aliexpress canceled my order for the flexible tube, so I had to use a regular pvc tube, which I glued with hot glue to the base. I was also unable to use all PCB clips for the LED PCB, as the resistors I used were interfering with the clips, so I just used the top clip which was barely enough to hold the PCB in place. I also added some hot glue, so it wouldn't fall off.
Also, by accident, it creates a cool octagonal pattern on the wall, which I really like.



**Total time spent: 4h**

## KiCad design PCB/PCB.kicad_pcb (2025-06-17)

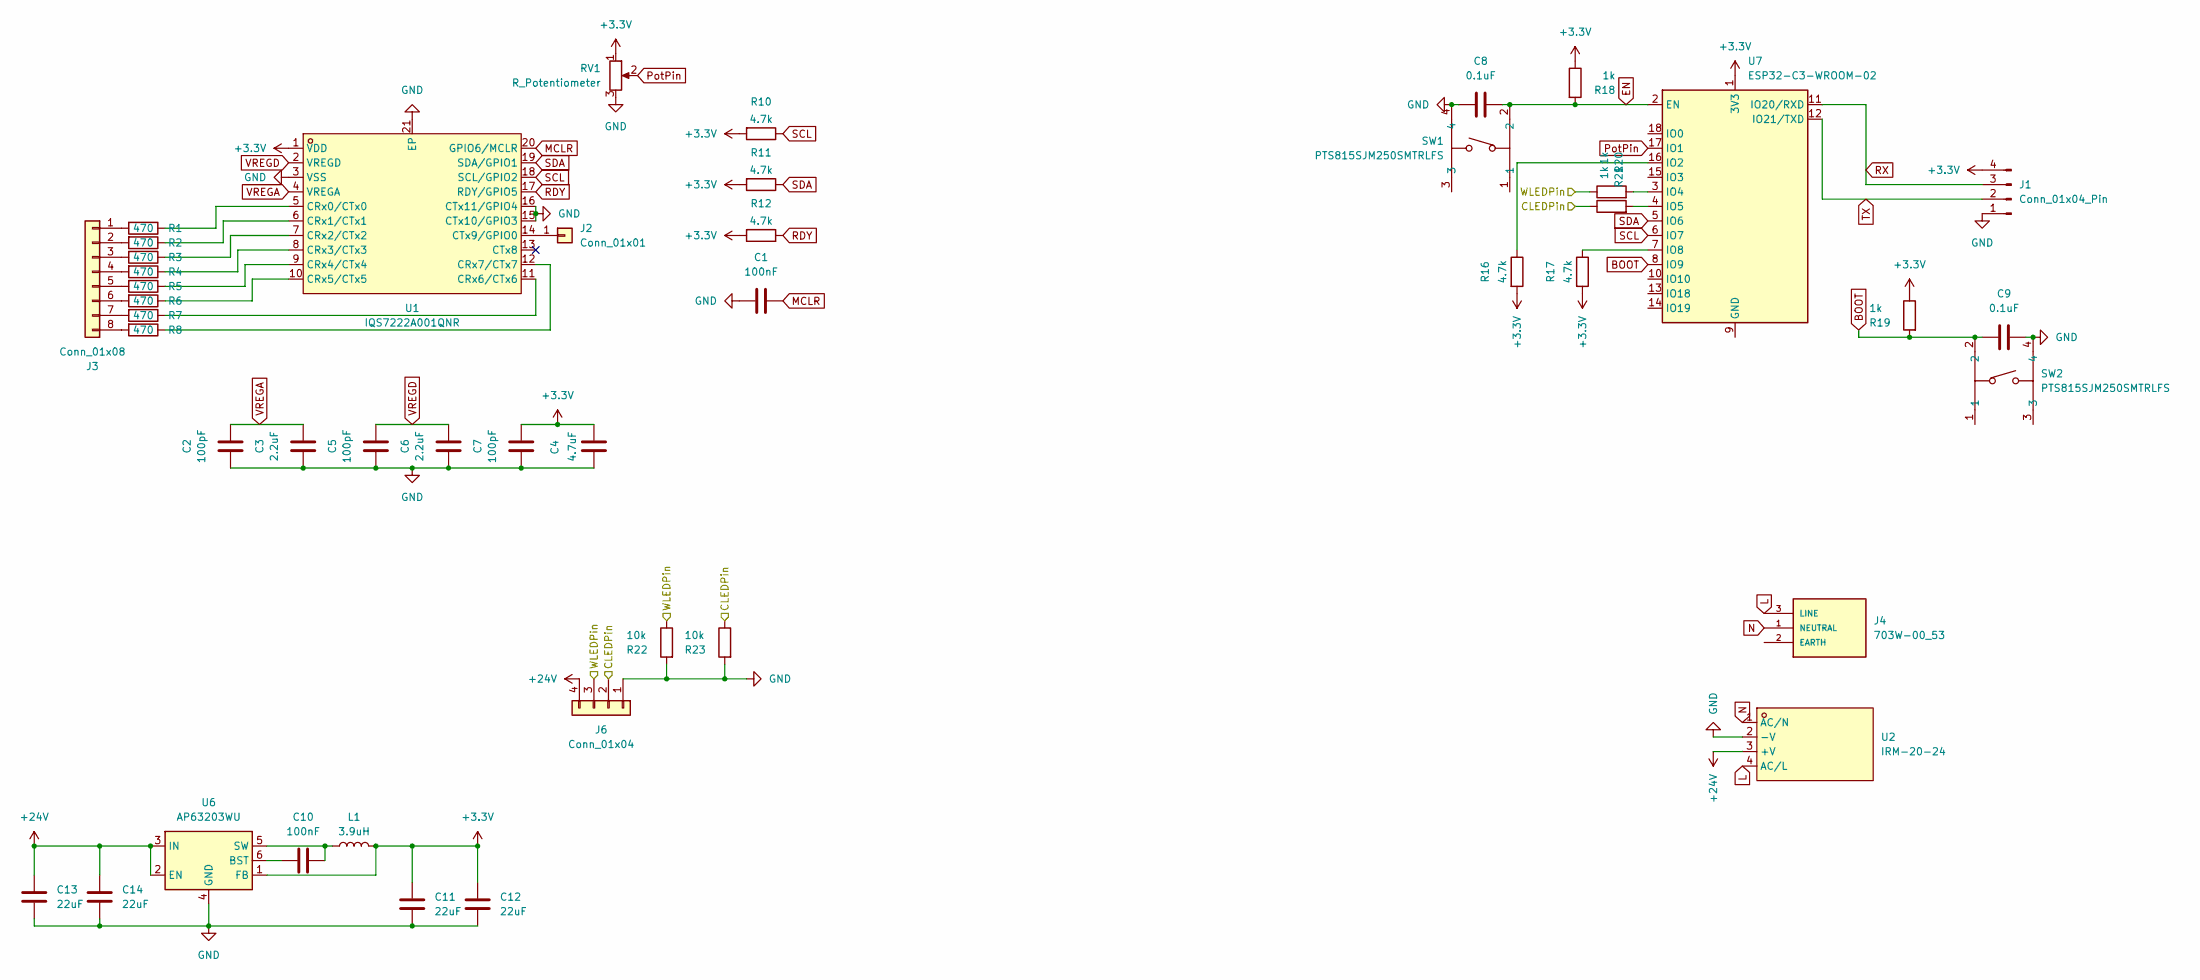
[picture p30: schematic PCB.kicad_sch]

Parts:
C1, C10: 100nF; C_0603_1608Metric
C2, C5, C7: 100pF; C_0603_1608Metric
C3, C6: 2.2uF; C_0603_1608Metric
C4: 4.7uF; C_0603_1608Metric
C8, C9: 0.1uF; C_0603_1608Metric
C11, C12, C13, C14: 22uF; C_0603_1608Metric
J1: Conn_01x04_Pin; PinHeader_1x04_P2.54mm_Vertical
J2: Conn_01x01; PinHeader_1x01_P2.54mm_Vertical
J3: Conn_01x08; TouchSlider-8_50x20mm
J4: 703W-00_53; QUALTEK_703W-00_53
J6: Conn_01x04; JST_XH_B4B-XH-AM_1x04_P2.50mm_Vertical
L1: 3.9uH; IND-SMD_L5.8-W5.8
R1, R2, R3, R4, R5, R6, R7, R8: 470; R_0603_1608Metric
R10, R11, R12, R16, R17: 4.7k; R_0603_1608Metric
R18, R19, R20, R21: 1k; R_0603_1608Metric
R22, R23: 10k; R_0603_1608Metric
RV1: R_Potentiometer; PinHeader_1x03_P2.54mm_Horizontal
SW1, SW2: PTS815SJM250SMTRLFS; KEY-SMD_4P-L4.2-W3.25-P2.15-TL; LCSC Part C2689510
U1: IQS7222A001QNR; WQFN-20_L3.0-W3.0-P0.40-BL-EP1.7; LCSC Part C3827627
U2: IRM-20-24; PWRM-TH_IRM-20-24; LCSC Part C194964
U6: AP63203WU; TSOT-23-6
U7: ESP32-C3-WROOM-02

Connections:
+3.3V: C4.2, C7.2, C11.2, C12.2, J1.4, L1.2, R10.2, R11.2, R12.2, R16.2, R17.2, R18.1, R19.1, RV1.1, U1.1 (VDD), U6.1 (FB), U7.1 (3V3)
+24V: C13.2, C14.2, J6.4, U2.3 (+V), U6.2 (EN), U6.3 (IN)
/Main PCB/CLEDPin: J6.2, R21.1, R23.1
/Main PCB/WLEDPin: J6.3, R20.1, R22.1
BOOT: C9.1, R19.2, SW2.2, U7.8 (IO9)
EN: C8.1, R18.2, SW1.2, U7.2 (EN)
GND: C1.1, C2.1, C3.1, C4.1, C5.1, C6.1, C7.1, C8.2, C9.2, C11.1, C12.1, C13.1, C14.1, J1.1, J6.1, R22.2, R23.2, RV1.3, SW1.4, SW2.4, U1.3 (VSS), U1.15 (CTx10/GPIO3), U1.16 (CTx11/GPIO4), U1.21 (EP), U2.2 (-V), U6.4 (GND)
L: J4.3 (LINE), U2.4 (AC/L)
MCLR: C1.2, U1.20 (GPIO6/MCLR)
N: J4.1 (NEUTRAL), U2.1 (AC/N)
unnamed: J2.1, U1.14 (CTx9/GPIO0)
unnamed: J3.1, R1.2
unnamed: J3.2, R2.2
unnamed: J3.3, R3.2
unnamed: J3.4, R4.2
unnamed: J3.5, R5.2
unnamed: J3.6, R6.2
unnamed: J3.7, R7.2
unnamed: J3.8, R8.2
unnamed: R1.1, U1.5 (CRx0/CTx0)
unnamed: R2.1, U1.6 (CRx1/CTx1)
unnamed: R3.1, U1.7 (CRx2/CTx2)
unnamed: R4.1, U1.8 (CRx3/CTx3)
unnamed: R5.1, U1.9 (CRx4/CTx4)
unnamed: R6.1, U1.10 (CRx5/CTx5)
unnamed: R7.1, U1.11 (CRx6/CTx6)
unnamed: R8.1, U1.12 (CRx7/CTx7)
unnamed: C10.1, U6.6 (BST)
unnamed: C10.2, L1.1, U6.5 (SW)
unnamed: U7.9 (GND), U7.19 (GND)
unnamed: R16.1, U7.16 (IO2)
unnamed: R20.2, U7.3 (IO4)
unnamed: R21.2, U7.4 (IO5)
unnamed: R17.1, U7.7 (IO8)
PotPin: RV1.2, U7.17 (IO1)
RDY: R12.1, U1.17 (RDY/GPIO5)
RX: J1.3, U7.11 (IO20/RXD)
SCL: R10.1, U1.18 (SCL/GPIO2), U7.6 (IO7)
SDA: R11.1, U1.19 (SDA/GPIO1), U7.5 (IO6)
TX: J1.2, U7.12 (IO21/TXD)
VREGA: C2.2, C3.2, U1.4 (VREGA)
VREGD: C5.2, C6.2, U1.2 (VREGD)

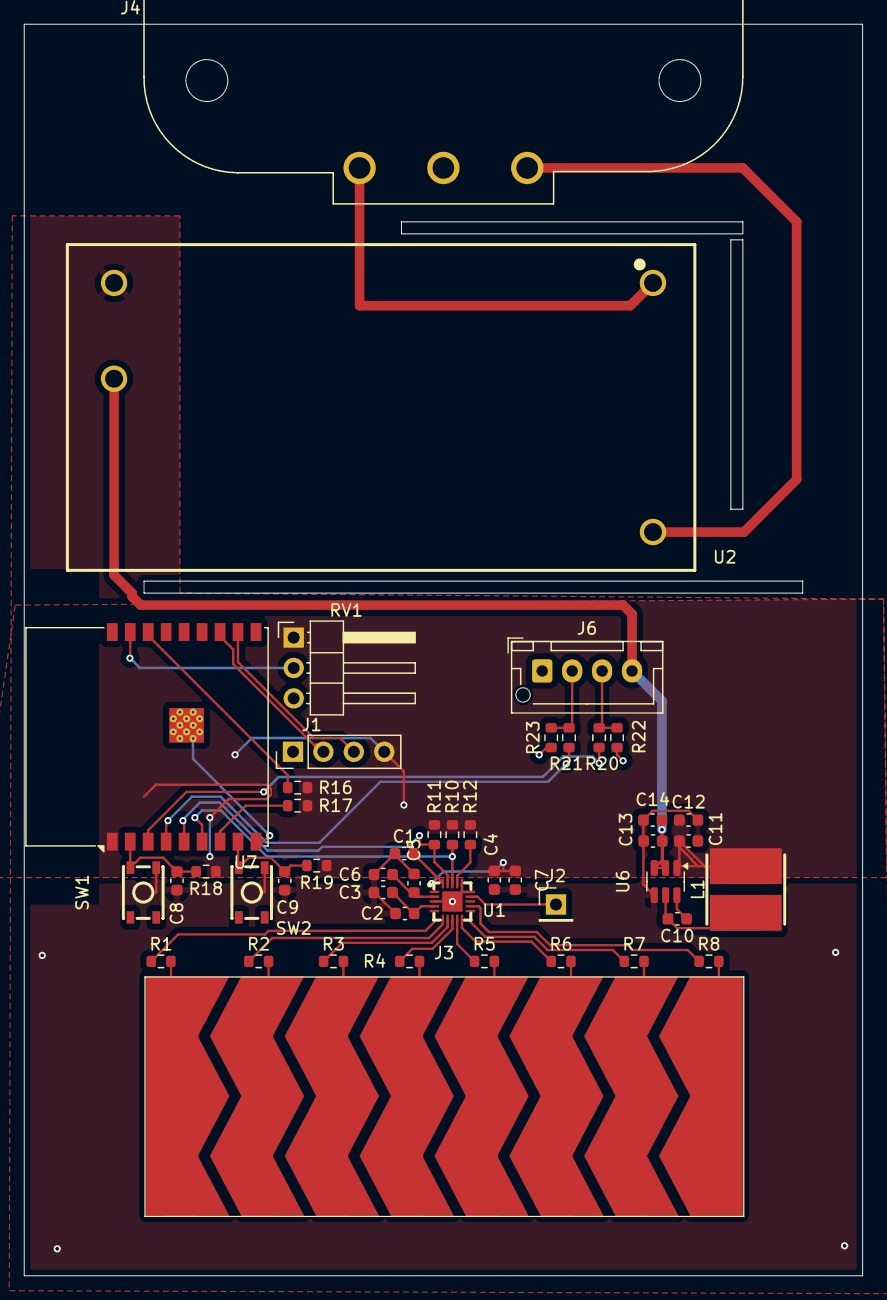
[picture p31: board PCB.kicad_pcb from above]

Board: 2 copper layers, 70.0 x 104.5 mm, 46 parts (0 on the bottom side), 42 nets.

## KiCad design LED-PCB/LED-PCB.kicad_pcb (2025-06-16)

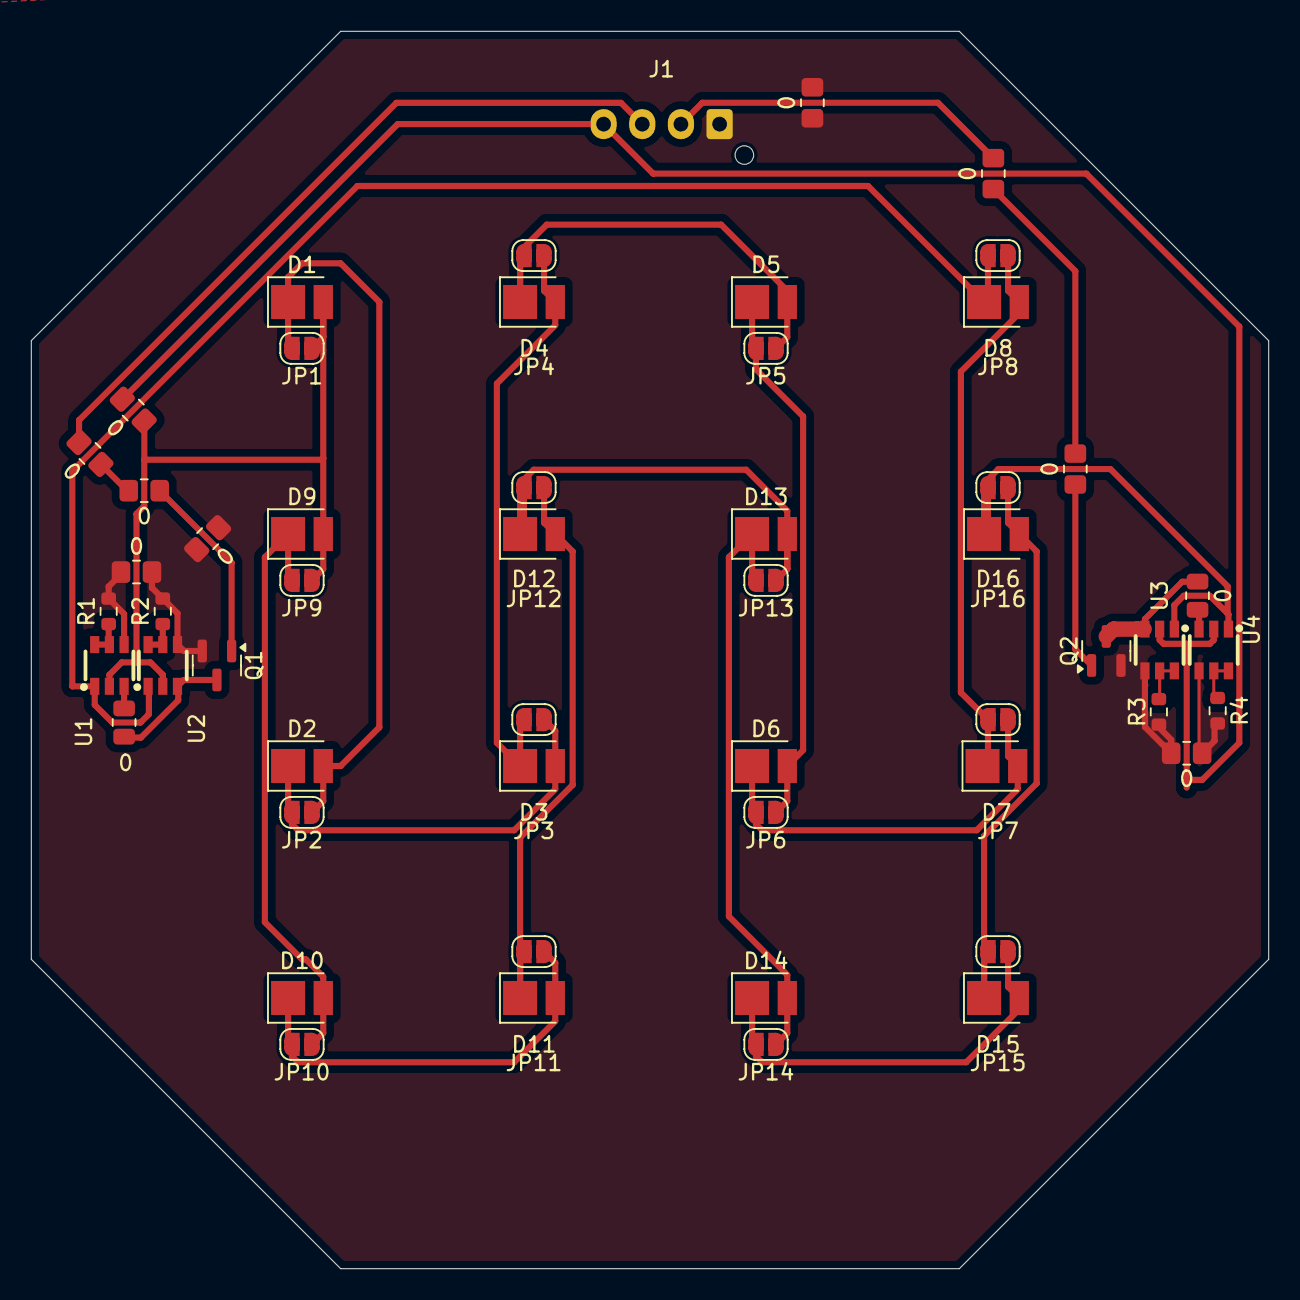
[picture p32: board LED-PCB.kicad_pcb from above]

Board: 2 copper layers, 80.0 x 80.0 mm, 54 parts (1 on the bottom side), 26 nets.

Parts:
0, 0#8: 0; R_0805_2012Metric
0#2, 0#3, 0#4, 0#5, 0#6, 0#7, 0#9, 0#10, 0#11: R_0805_2012Metric_Pad1.20x1.40mm_HandSolder
D1, D2, D3, D4, D5, D6, D7, D8: LEDW; LED_PLCC_2835
D9, D10, D11, D12, D13, D14, D15, D16: LEDC; LED_PLCC_2835
J1: Conn_01x04; JST_XH_B4B-XH-AM_1x04_P2.50mm_Vertical
JP1, JP2, JP3, JP4, JP5, JP6, JP7, JP8, JP9, JP10, JP11, JP12, JP13, JP14, JP15, JP16: SolderJumper_2_Open; SolderJumper-2_P1.3mm_Open_RoundedPad1.0x1.5mm
Q1, Q2: 2N7002; SOT-23
R1, R2, R3, R4: 9.1; R_0603_1608Metric
U1, U2, U3, U4: AL5802-7; SOT-23-6_L2.9-W1.6-P0.95-LS2.8-BR

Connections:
+24V: 0#4.1, 0#4.2, D1.2 (A), D9.2 (A), J1.4, JP1.1 (A), JP9.1 (A), U1.2, U2.2, U3.2, U4.2
/CLEDPin: 0#2.1, 0#2.2, 0#3.1, 0#3.2, J1.2, Q2.1 (G)
/WLEDPin: 0#6.1, 0#6.2, 0#11.1, 0#11.2, J1.3, Q1.1 (G)
GND: 0#5.1, 0#5.2, 0#7.1, 0#7.2, 0#9.1, 0#9.2, 0#10.1, 0#10.2, J1.1, Q1.2 (S), Q2.2 (S), R1.2, R2.2, R3.2, R4.2, U1.4, U2.4, U3.4, U4.4
unnamed: D1.1 (K), D2.2 (A), JP1.2 (B), JP2.1 (A)
unnamed: D2.1 (K), D3.2 (A), JP2.2 (B), JP3.1 (A)
unnamed: D3.1 (K), D4.2 (A), JP3.2 (B), JP4.1 (A)
unnamed: D4.1 (K), D5.2 (A), JP4.2 (B), JP5.1 (A)
unnamed: D5.1 (K), D6.2 (A), JP5.2 (B), JP6.1 (A)
unnamed: D6.1 (K), D7.2 (A), JP6.2 (B), JP7.1 (A)
unnamed: D7.1 (K), D8.2 (A), JP7.2 (B), JP8.1 (A)
unnamed: D8.1 (K), JP8.2 (B), U1.1, U2.1
unnamed: D9.1 (K), D10.2 (A), JP9.2 (B), JP10.1 (A)
unnamed: D10.1 (K), D11.2 (A), JP10.2 (B), JP11.1 (A)
unnamed: D11.1 (K), D12.2 (A), JP11.2 (B), JP12.1 (A)
unnamed: D12.1 (K), D13.2 (A), JP12.2 (B), JP13.1 (A)
unnamed: D13.1 (K), D14.2 (A), JP13.2 (B), JP14.1 (A)
unnamed: D14.1 (K), D15.2 (A), JP14.2 (B), JP15.1 (A)
unnamed: D15.1 (K), D16.2 (A), JP15.2 (B), JP16.1 (A)
unnamed: D16.1 (K), JP16.2 (B), U3.1, U4.1
unnamed: 0#8.1, 0#8.2, Q1.3 (D), U1.3, U2.3
unnamed: 0.1, 0.2, Q2.3 (D), U3.3, U4.3
unnamed: R1.1, U1.5, U1.6
unnamed: R2.1, U2.5, U2.6
unnamed: R3.1, U3.5, U3.6
unnamed: R4.1, U4.5, U4.6

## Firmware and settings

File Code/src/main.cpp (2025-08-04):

#include <Arduino.h>
#include <Wire.h>

void setup() {
    Wire.begin();
    Serial.begin(115200);
    while (!Serial); // Wait for Serial to be ready
    Serial.println("\nI2C Scanner");
}

void loop() {
    byte error, address;
    int nDevices = 0;

    Serial.println("Scanning...");

    for (address = 1; address < 127; address++) {
        Wire.beginTransmission(address);
        error = Wire.endTransmission();

        if (error == 0) {
            Serial.print("I2C device found at address 0x");
            if (address < 16)
                Serial.print("0");
            Serial.print(address, HEX);
            Serial.println(" !");
            nDevices++;
        } else if (error == 4) {
            Serial.print("Unknown error at address 0x");
            if (address < 16)
                Serial.print("0");
            Serial.println(address, HEX);
        }
    }
    if (nDevices == 0)
        Serial.println("No I2C devices found\n");
    else
        Serial.println("done\n");

    delay(5000); // Wait 5 seconds before next scan
}

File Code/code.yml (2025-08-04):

esphome:
  name: smartdesklight
  friendly_name: SmartDeskLight

esp32:
  board: esp32-c3-devkitm-1
  framework:
    type: esp-idf

# Enable logging
logger:

# Enable Home Assistant API
api:
  encryption:
    key: "P7qBQLNfuUfGNQnKlKD6rNeGyw2JZVsd/D/J4DKRQb0="

ota:
  - platform: esphome
    password: "38e0c6cc718e9151f90641751df664e9"

wifi:
  ssid: !secret wifi_ssid_m
  password: !secret wifi_password_m 

  # Enable fallback hotspot (captive portal) in case wifi connection fails
  ap:
    ssid: "desklight Fallback Hotspot"
    password: "wHjqyQOLnaPa"

light:
  - platform: cwww
    name: "Livingroom Lights"
    cold_white: WLight
    warm_white: CLight
    cold_white_color_temperature: 6500 K
    warm_white_color_temperature: 2200 K

output:
  - platform: ledc
    id: CLight
    pin: GPIO4
    frequency: 1000 Hz
    zero_means_zero: true
    min_power: 0.0
    inverted: true
  - platform: ledc
    id: WLight
    pin: GPIO5
    frequency: 1000 Hz
    zero_means_zero: true
    inverted: true
    min_power: 0.0

captive_portal:

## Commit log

2025-06-18 add images + readme
    [BOM.csv]
2025-06-18 ready for highway
    [BOM.csv]
2025-08-04 working code
    [partitions.csv]
2025-08-06 finish project
    [Lamp.step]
